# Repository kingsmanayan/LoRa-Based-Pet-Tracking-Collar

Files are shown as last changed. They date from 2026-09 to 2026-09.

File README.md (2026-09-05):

# PAW — LoRa-Based Pet Tracking Collar

A battery-powered pet tracking collar that reports location over a private
868 MHz LoRa P2P link — no SIM, no cellular modem. A gateway board bridges
received LoRa packets onto MQTT so a mobile app can show live locations on a
map.

This repo contains all three parts of the assignment: the collar + gateway
hardware, the collar firmware, and the LoRa→MQTT bridge with an app-side
subscriber. `PAW_Full_Project_Documentation.docx` is the single consolidated
write-up; this README is the map of the repo and the "how do I run this"
guide.

## Repository structure

```
paw-hometask/
├── PAW_Full_Project_Documentation.pdf   ← consolidated project doc (start here)
├── README.md                             ← this file
├── part1-hardware/
│   ├── collar/
│   │   ├── LoRa_Based_Pet_Collar
│   │   │   ├──LoRa_Based_Pet_Collar.Kicad Schematric       ← collar main board KaiCad schematic
│   │   ├── collar_schematic.pdf / .jpg   ← collar main board schematic
│   │   ├── BOM_Pet_Tracking_Collar.pdf  ← collar bill of materials (₹3,696/unit)
│   │   └── Collar_Design_Notes.pdf      ← antenna placement, power budget, 1,000-unit changes
│   └── bridge/
│   │   ├── LoRa_Reciver_End_Bridge_part
│   │   │   ├──LORA_Bridge_part.Kicad Schematric       ← gateway (ESP32 + RAK3172) KaiCad schematic
│       ├── bridge_schematic.pdf / .jpg   ← gateway (ESP32 + RAK3172) schematic
│       ├── BOM_LoRa_Bridge_Receiver.pdf ← gateway bill of materials (₹2,102/unit)
│       └── Bridge_Design_Notes.pdf      ← antenna placement, power budget, 1,000-unit changes
├── part2-firmware/
│   ├── collar_firmware.cpp               ← collar firmware (RUI3 APIs, RAK3172)
│   ├── PAW_Technical_Document.pdf       ← architecture, state machine, deliverables summary
│   ├── PAW_Binary_Packet_Specification.pdf ← 18-byte packet layout + encode/decode reference
│   ├── PAW_LoRa_Radio_Configuration.pdf ← SF/CR/BW/power rationale, airtime, ETSI duty-cycle check
│   └── PAW_Power_Optimization_Strategy.pdf ← 7-point power design + battery-life scenarios
└── part3-bridge/
    ├── gateway_bridge.ino                ← ESP32 firmware: RAK3172 UART → decode → MQTT publish
    ├── MQTT_SCHEMA.md                    ← topic structure, payload schema, QoS rationale
    └── app_subscriber.dart               ← Flutter MQTT subscriber (mqtt_client package)
```

## What's real vs. simulated/stubbed

| Component | Status |
|---|---|
| Collar schematic (KiCad-style, hand-drawn to PDF) | Real, complete circuit |
| Collar firmware — accelerometer wake, sleep, packet build, LoRa TX | Real logic, targets real RUI3 APIs |
| Collar firmware — GPS acquisition | **Mockable.** `HW_GPS_MOCK` build switch (`collar_firmware.cpp`, top of file). `1` = simulated jittered fix (bench-test default); `0` = real NMEA `$GxGGA` parsing over UART, already implemented and ready for hardware |
| Collar firmware — LoRa TX | **Mockable.** `HW_LORA_MOCK` build switch. `1` = logs the packet instead of radioing it (bench test without a radio); `0` (default) = real `api.lora.psend()` |
| Gateway schematic | Real, complete circuit |
| Gateway bridge firmware | Real logic (WiFi/MQTT reconnect state machine, AT-command RAK3172 config, hex packet decode). **Not bench-tested against a live RAK3172 serial stream** — see Open Items below for the one field-format assumption that needs confirming against real hardware |
| MQTT broker | Not run/hosted as part of this submission — `gateway_bridge.ino` targets a public test broker (`broker.hivemq.com`) by default; point `MQTT_HOST` at your own broker (Mosquitto, HiveMQ Cloud, etc.) for anything beyond a bench test |
| App-side subscriber | Real, working Dart/Flutter code against the `mqtt_client` package — not wired into a full map UI, since the task asks for the subscription layer, not a complete app |
| Battery-life figures | **Engineering estimates**, not measurements — every current-draw number is a datasheet-typical value, clearly labeled as such in `PAW_Power_Optimization_Strategy.docx`. No physical hardware was available to measure real current draw or real per-animal duty cycle |

## How to run each part

### Part 1 — Hardware
Open `part1-hardware/collar/collar_schematic.pdf` and `part1-hardware/bridge/bridge_schematic.pdf`
directly (or the `.jpg` renders for a quick look without a PDF viewer). BOM and design-notes
documents are standard `.docx`, viewable in Word / LibreOffice / Google Docs.

### Part 2 — Firmware (collar)
Target: RAKwireless RAK3172 (STM32WLE5), built through the Arduino IDE with the RAKwireless
RUI3 board package installed (`RAK3172` board target).

1. Install the RUI3 Arduino board package (RAKwireless documentation) and select the RAK3172 board.
2. Open `part2-firmware/collar_firmware.cpp` in a sketch folder of the same name (Arduino requires
   the `.ino`/`.cpp` filename to match its containing folder — rename the folder or the file to suit).
3. Leave `HW_GPS_MOCK 1` and `HW_LORA_MOCK 0` to bench-test the full wake→fix→pack→transmit→sleep
   cycle over a real LoRa radio with a simulated GPS fix. Flip `HW_GPS_MOCK` to `0` once a MAX-M10S
   is wired to `Serial1`.
4. Flash and open the serial monitor at 115200 baud to watch the wake/fix/TX log lines.

### Part 3 — MQTT bridge
Target: any ESP32 dev board (schematic assumes an ESP32-DEVKIT-V1) wired to a RAK3172 over UART2
(pins 16/17), with the RAK3172 configured for continuous LoRa P2P receive.

1. Arduino IDE with ESP32 board support, plus the `AsyncMqttClient` and `ArduinoJson` libraries.
2. In `part3-bridge/gateway_bridge.ino`, set `WIFI_SSID` / `WIFI_PASSWORD` and, if not using the
   default public test broker, `MQTT_HOST` / `MQTT_USERNAME` / `MQTT_PASSWORD`.
3. Flash to the ESP32. On boot it configures the RAK3172 over AT commands (`AT+P2P=...`,
   `AT+PRECV=65534` for continuous RX) and begins forwarding decoded packets to
   `paw/collar/{device_id}/location` — see `MQTT_SCHEMA.md` for the full payload shape and the
   QoS-1 / retained rationale.
4. To bench-test without real LoRa hardware, inject a mock `+EVT:RXP2P:<rssi>:<snr>:<hex>` line on
   the UART the ESP32 reads from `RAKSerial` (e.g. from a second microcontroller or a USB-serial
   adapter looped into pin 16), using a hex payload produced by `PAW_Binary_Packet_Specification.docx`'s
   worked example.
5. App side: add `mqtt_client: ^10.0.0` to a Flutter project's `pubspec.yaml`, drop in
   `part3-bridge/app_subscriber.dart`, and call `PawMqttService(broker: '<your broker>',
   onLocationUpdate: ...).connect()`.

## Assumptions

- No physical hardware (RAK3172, MAX-M10S, LIS2DE12, ESP32) was available during this work —
  all firmware is written against real RUI3/Arduino APIs and is structured to run unmodified on
  the target hardware, but has only been exercised via the mock switches described above.
- LoRa P2P (not LoRaWAN) is used throughout, matching the assignment's "talks directly to the
  owner's phone... and to a home LoRaWAN gateway" framing loosely — the gateway in this submission
  receives LoRa P2P packets directly rather than acting as a full LoRaWAN network-server gateway,
  which is simpler to implement end-to-end within the timebox and still satisfies "gets a location
  fix into a mobile app over MQTT."
- Component prices in both BOMs are indicative single-unit distributor prices in INR as of
  September 2026 and exclude GST, assembly labour, and enclosure hardware (noted in each BOM).
- MQTT broker is assumed pre-existing infrastructure (a public test broker is wired in by default)
  rather than something this submission stands up itself.

## Open items / known inconsistencies

Working across the hardware, firmware, and bridge documents surfaced a few real inconsistencies
worth flagging rather than quietly resolving one way or the other — see
**Section 7 (Cross-Document Consistency Review)** of `PAW_Full_Project_Documentation.docx` for the
full list with reasoning. The two most consequential:

1. **The battery-life headline figures assume a regulator that isn't in the current BOM.**
   `PAW_Power_Optimization_Strategy.docx` models ~3 µA sleep current (a low-IQ regulator), but the
   collar schematic/BOM currently specifies an **AMS1117 LDO**, whose own datasheet-typical ~5 mA
   quiescent draw is called out in `Collar_Design_Notes.docx` as "the single biggest lever on
   standby battery life." At 5 mA continuous, a 1,000 mAh cell would deplete in roughly **8 days**
   regardless of GPS/LoRa activity — nowhere near the 6–8 month figures quoted elsewhere. The
   low-IQ regulator swap is listed as a production TODO in the design notes; until it's made, the
   long-runtime figures describe the production revision, not the schematic as currently drawn.
2. **LoRa bandwidth is never set explicitly in the collar firmware.** `hal_lora_init()` has no
   bandwidth call, so it relies on an unstated RUI3 P2P default (assumed 125 kHz). The gateway
   firmware does set it explicitly (`LORA_BW=125`), which is indirect evidence the link works at
   125 kHz — but the collar side should set it explicitly too, since an unstated default is one
   library update away from silently breaking the link.

## What I'd do differently with more time

- Get real hardware on the bench to replace every datasheet-typical current figure with a measured
  one, and to confirm the actual `+EVT:RXP2P` field format the target RUI3 firmware version emits
  (flagged directly in `gateway_bridge.ino`'s comments).
- Resolve the regulator/battery-life mismatch above by re-running the Section 6/7 battery scenarios
  against the AMS1117's real quiescent current, or by moving the low-IQ regulator into the current
  BOM instead of deferring it to the 1,000-unit revision.
- Wire up the payload fields `MQTT_SCHEMA.md` documents but `gateway_bridge.ino` currently leaves
  commented out (`rssi`, `snr`, `gps_valid`, `motion_wake`, `seq`) — and fix `app_subscriber.dart`'s
  `CollarLocation`, which references `location.seq` for de-dup but never declares or parses a `seq`
  field, so that logic doesn't currently compile/run end-to-end.
- Give the collar an RTC or have the gateway stamp `ts` on receipt, so the map can show wall-clock
  time instead of seconds-since-boot.
- Add battery discharge protection to the collar (TP4056 only manages charging) and a defined
  input/regulation stage to the gateway board (its schematic currently assumes a bare 3.3 V rail
  with no shown supply path) before either design is production-ready.

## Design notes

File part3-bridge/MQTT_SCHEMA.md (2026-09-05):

# PAW Collar — MQTT Topic & Payload Schema

## 1. Topic structure

| Topic | Purpose | Retained? |
|---|---|---|
| `paw/collar/{device_id}/location` | Latest location update from one collar | Yes |
| `paw/collar/gateway/status` | Gateway online/offline (LWT) | Yes |

- `{device_id}` is the single-byte `DEVICE_ID` from the tracker firmware, published as a decimal string (e.g. `paw/collar/1/location`).
- The app subscribes to `paw/collar/+/location` to track every collar on one connection, or to a specific `paw/collar/1/location` if it only cares about one pet.
- `paw/collar/gateway/status` payload is the plain string `online` or `offline` (set via MQTT Last Will and Testament, so a crashed or disconnected gateway is reported automatically by the broker).

## 2. Location payload

```json
{
  "lat": 52.4104,
  "lon": 12.9738,
  "ts": 1735689600,
  "battery_mv": 3850,
  "source": "gateway",
 
}
```

| Field | Type | Description |
|---|---|---|
| `lat` | float | Latitude, decimal degrees |
| `lon` | float | Longitude, decimal degrees |
| `ts` | uint32 | Seconds since collar boot (see note below — not wall-clock UTC in the current tracker firmware) |
| `battery_mv` | uint16 | Collar battery voltage, millivolts |
| `source` | string | Always `"gateway"` — reserved for future multi-gateway dedup | 
| `rssi` | int | Signal strength of the received LoRa packet, dBm |
| `snr` | int | Signal-to-noise ratio of the received LoRa packet, dB |
| `gps_valid` | bool | Whether the collar had a real fix when it sent this packet |
| `motion_wake` | bool | `true` if this update was triggered by the accelerometer, `false` if it's the periodic 30-minute update |
| `seq` | uint8 | Rolling per-collar sequence number (0–255, wraps), useful for detecting dropped packets |

**Note on `ts`:** the current tracker firmware sets `gps_timestamp = millis() / 1000`, i.e. seconds since the collar last rebooted — not a real UTC epoch. If you need wall-clock time on the map, either read the NMEA `$GxGGA` time field into the packet, add an RTC to the tracker, or have the gateway stamp `ts` itself on receipt (accepting LoRa transit delay, which is sub-second and usually fine for a pet tracker).

## 3. QoS choice: **QoS 1, retained**

| QoS | Guarantee | Why (not) here |
|---|---|---|
| 0 | At-most-once, fire-and-forget | Rejected — LoRa fixes are expensive to reacquire (GPS cold-start can take up to a minute, and each transmission costs battery). Silently dropping a location update on a flaky Wi-Fi hop between gateway and broker isn't worth the marginal latency savings. |
| **1** | **At-least-once** | **Chosen.** Guarantees the update reaches the broker even across a brief gateway/broker disconnect (the broker re-delivers until PUBACK). Possible duplicate deliveries are harmless here — each message fully overwrites the previous location, so re-processing the same fix twice on the app side is a no-op. |
| 2 | Exactly-once | Rejected — the extra handshake (PUBREC/PUBREL/PUBCOMP) costs more round-trips and broker-side state for a benefit (dedup) the app doesn't need, since duplicate location messages are idempotent by nature. |

**Retain = true rationale:** the tracker only transmits every 30 minutes (or on motion). Without retain, a mobile app that opens or reconnects has to wait up to 30 minutes to see anything. With retain, the broker immediately replays the last known location for that topic the instant the app subscribes — the map is populated on open, not on the next transmission.

## 4. Suggested extension (multi-gateway dedup)

If you add a second gateway later, use `seq` + `device_id` (and optionally the tracker's own `ts`) to de-duplicate the same over-the-air packet received by two gateways at once, since `source` alone won't disambiguate.

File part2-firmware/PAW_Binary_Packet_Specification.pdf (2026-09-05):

# PAW

# Binary Packet Specification

### 18-Byte Little-Endian LoRa Payload Format

Reference Encoding & Decoding Implementation

Version 1.0
September 2026

PAW – Binary Packet Specification

Version 1.0 | Page 2 of 5

## 1. Overview

This document specifies the 18-byte binary payload transmitted by the PAW collar over LoRa P2P, and provides a reference implementation for both sides of the link: the C encoder used in the collar firmware, and a Python decoder suitable for a gateway or backend receiving the packets. All multi-byte fields use little-endian byte order.

## 2. Packet Layout

Byte | Field | Type | Description
0 | Device ID | uint8 | Unique collar identifier
1 | Protocol Version | uint8 | Packet format version
2 | Status Flags | uint8 | Bit 0: GPS valid Bit 1: motion-triggered wake
3–6 | Latitude | int32 | Degrees × 1,000,000
7–10 | Longitude | int32 | Degrees × 1,000,000
11–14 | Timestamp | uint32 | Seconds since boot
15–16 | Battery | uint16 | Battery voltage, millivolts
17 | Sequence | uint8 | Packet sequence number (wraps at 256)

Total payload size: 18 bytes. Encoding: little-endian.

## 3. Worked Example

The sample field values below encode to the following 18-byte payload, shown as hex octets:

Field | Sample Value
device_id | 1
protocol_version | 1
flags | 3 (GPS valid = 1, motion wake = 1)
latitude | 22.864000
longitude | 88.401000
timestamp | 123456
battery_mv | 3785
sequence | 42

Encoded bytes (hex):

01 01 03 80 E0 5C 01 68 E4 44 05 40 E2 01 00 C9 0E 2A

18 bytes, little-endian. Byte 0 = 01 (device_id) … byte 17 = 2A (sequence = 42).

## 4. Reference Encoder (C — Collar Firmware)

This is the exact packing routine used on the collar (RUI3 / Arduino-compatible C++), reproduced from collar_firmware.cpp:

// Encodes the current GPS / battery / sequence state into an 18-byte // little-endian PAW packet. Matches collar_firmware.cpp exactly.

static inline void writeLE32(uint8_t *buf, int32_t value) {
buf[0] = value & 0xFF;
buf[1] = (value >> 8) & 0xFF;
buf[2] = (value >> 16) & 0xFF;
buf[3] = (value >> 24) & 0xFF;
}

static inline void writeLE16(uint8_t *buf, uint16_t value) { buf[0] = value & 0xFF;
buf[1] = (value >> 8) & 0xFF;
}

static uint8_t buildPacket(uint8_t *packet, bool motionWake) { int32_t lat_e6 = (int32_t)(g_gps_lat * 1000000.0); int32_t lon_e6 = (int32_t)(g_gps_lon * 1000000.0);

packet[0] = DEVICE_ID;
packet[1] = PROTOCOL_VERSION;

packet[2] = 0;
if (g_gps_valid) packet[2] |= (1 << 0); if (motionWake) packet[2] |= (1 << 1);

writeLE32(&packet[3], lat_e6); writeLE32(&packet[7], lon_e6);
writeLE32(&packet[11], (int32_t)g_gps_timestamp); writeLE16(&packet[15], g_battery_mv);
packet[17] = g_sequence++; // wraps at 256 by design (uint8_t)

return 18; // PACKET_LEN
}

Encoder: field values → 18-byte little-endian buffer.

## 5. Reference Decoder (C — Receiver / Gateway)

The receiving side inverts buildPacket() field-for-field: readLE32/readLE16 reassemble the little-endian byte groups, and the two status-flag bits are tested individually. PawPacket holds the result in the same field order as the packet layout in Section 2.

// Decodes an 18-byte PAW packet back into field values. // Mirrors buildPacket() byte-for-byte, in reverse.

static inline int32_t readLE32(const uint8_t *buf) {
return (int32_t)((uint32_t)buf[0] | |
((uint32_t)buf[1] << 8) |
((uint32_t)buf[2] << 16) | ((uint32_t)buf[3] << 24));
}

static inline uint16_t readLE16(const uint8_t *buf) {
return (uint16_t)(buf[0] | (buf[1] << 8));
}

typedef struct {
uint8_t device_id;
uint8_t protocol_version;
bool | gps_valid;
bool | motion_wake;
int32_t lat_e6; | // degrees x 1,000,000
int32_t lon_e6; | // degrees x 1,000,000
uint32_t timestamp; | // seconds since boot
uint16_t battery_mv;
uint8_t sequence;
} PawPacket;

static void decodePacket(const uint8_t *packet, PawPacket *out) {
out->device_id | = packet[0];
out->protocol_version = packet[1];

out->gps_valid = (packet[2] & (1 << 0)) != 0; out->motion_wake = (packet[2] & (1 << 1)) != 0;

out->lat_e6 | = readLE32(&packet[3]);
out->lon_e6 | = readLE32(&packet[7]);
out->timestamp = (uint32_t)readLE32(&packet[11]); out->battery_mv = readLE16(&packet[15]); out->sequence = packet[17];
}

Decoder: 18-byte little-endian buffer → PawPacket struct. Exact inverse of buildPacket().

## 6. Line-by-Line Walkthrough

This section traces every line of buildPacket() and decodePacket() against the exact worked-example values from Section 3, so each transformation from field value ↔ byte is shown explicitly rather than asserted.

### 6.1 Encoding: buildPacket()

Code | What happens with this packet's data
lat_e6 = (int32_t)(g_gps_lat * 1000000.0); | 22.864000 × 1,000,000 = 22864000 (0x015CE080). Stored LE → bytes[3..6] = 80 E0 5C 01.
lon_e6 = (int32_t)(g_gps_lon * 1000000.0); | 88.401000 × 1,000,000 = 88401000 (0x0544E468). Stored LE → bytes[7..10] = 68 E4 44 05.
packet[0] = DEVICE_ID; | device_id = 1 → byte[0] = 01.
packet[1] = PROTOCOL_VERSION; | protocol_version = 1 → byte[1] = 01.

Code | What happens with this packet's data
packet[2] = 0; if (gps_valid) packet[2] |= (1<<0); if (motionWake) packet[2] |= (1<<1); | Both true → 0b00000001 | 0b00000010 = 0b00000011 → byte[2] = 03.
writeLE32(&packet[3], lat_e6); | 22864000 written least-significant-byte-first: 80, E0, 5C, 01 → bytes[3..6].
writeLE32(&packet[7], lon_e6); | 88401000 written LSB-first: 68, E4, 44, 05 → bytes[7..10].
writeLE32(&packet[11], (int32_t)g_gps_timestamp); | 123456 = 0x0001E240 → LSB-first: 40, E2, 01, 00 → bytes[11..14].
writeLE16(&packet[15], g_battery_mv); | 3785 = 0x0EC9 → LSB-first: C9, 0E → bytes[15..16].
packet[17] = g_sequence++; | sequence = 42 = 0x2A → byte[17] = 2A. g_sequence becomes 43 for the next packet.
return 18; | Full frame: 01 01 03 80 E0 5C 01 68 E4 44 05 40 E2 01 00 C9 0E 2A — matches Section 3 exactly.

### 6.2 Decoding: decodePacket()

Code | What happens with this packet's data
out->device_id = packet[0]; | byte[0] = 01 → device_id = 1.
out->protocol_version = packet[1]; | byte[1] = 01 → protocol_version = 1.
out->gps_valid = (packet[2] & (1<<0)) != 0; | byte[2] = 03 = 0b011. Bit 0 set → gps_valid = true.
out->motion_wake = (packet[2] & (1<<1)) != 0; | Bit 1 of 0b011 also set → motion_wake = true.
out->lat_e6 = readLE32(&packet[3]); | Bytes 80 E0 5C 01 reassembled LSB-first → 0x015CE080 = 22864000 → lat = 22.864000°.
out->lon_e6 = readLE32(&packet[7]); | Bytes 68 E4 44 05 → 0x0544E468 = 88401000 → lon = 88.401000°.
out->timestamp = (uint32_t)readLE32(&packet[11]); | Bytes 40 E2 01 00 → 0x0001E240 = 123456 seconds.
out->battery_mv = readLE16(&packet[15]); | Bytes C9 0E → 0x0EC9 = 3785 mV.
out->sequence = packet[17]; | byte[17] = 2A = 42, matching the value the encoder wrote.

Result: decodePacket() reproduces device_id, protocol_version, both flag bits, latitude, longitude, timestamp, battery_mv, and sequence exactly as they were before encoding — the two functions are byte-for-byte inverses of each other.

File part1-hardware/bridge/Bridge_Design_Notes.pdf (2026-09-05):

## DESIGN NOTES

### LoRa-Based MQTT Bridge (Receiver Side)

Antenna Placement · Power Budget · Production (1,000-Unit) Changes

### 1. Antenna Placement Rationale

- Single RF antenna on this board: the 868 MHz LoRa antenna (E2, ANT-868-PW-RA, tilt/swivel screw-mount whip, feeding RAK3172 U1's RF pin). Being an external screw-mount type rather than a PCB trace or chip antenna gives more placement freedom, but ground-plane extent and feed routing still matter for match and efficiency.
- Mounting & orientation: mount E2 at the enclosure edge, vertical, for the omnidirectional pattern typical of gateway/bridge installs. Keep it clear of metal enclosure panels, brackets, or standoffs, and away from the ESP32-DEVKIT-V1's own onboard antenna to avoid pattern distortion and detuning.
- Coexistence with ESP32 Wi-Fi: the ESP32-DEVKIT-V1 carries its own onboard 2.4 GHz Wi-Fi antenna a few centimetres from the RAK3172 and its 868 MHz antenna on the same board. The two bands don't overlap, but a strong Wi-Fi TX burst sitting that close to the LoRa RF front end can raise its noise floor and desensitize LoRa RX. Recommend physically separating the two modules on the PCB/enclosure and, if range is marginal, adding shielding or extra spacing between them.
- UART link routing: the ESP32–RAK3172 UART bridge (TX2/RX2 to PB6/PB7) should be routed short and kept away from the antenna feed line to avoid coupling RF noise into the digital signal.
- Enclosure material: if the gateway is housed in a metal enclosure, the whip antenna must protrude outside it (or the enclosure needs an RF-transparent window) — a fully metal box around a whip antenna will substantially attenuate the LoRa link.

### 2. Power Budget Estimate

Note: unlike the collar, this schematic shows no battery/charging section — the bridge is assumed to run from a continuous 5 V USB or DC supply feeding the 3.3 V rail shown. The estimate below frames the supply's current headroom rather than a battery runtime.

State | Dominant load | Approx. current
Idle / LoRa RX listen | ESP32 Wi-Fi connected & idle + RAK3172 continuous
| LoRa RX | ~80–120 mA (ESP32 Wi-Fi idle) + ~10–12 mA
| | (RAK3172 RX) ≈ 90–130 mA
Wi-Fi TX burst (MQTT publish) | ESP32 Wi-Fi radio driving an MQTT publish over the
| WLAN uplink | ~150–260 mA (peaks during association / TX)
LoRa TX burst (ack / downlink) | RAK3172 PA drive, if the bridge also transmits, ~14
| dBm typical up to +22 dBm boost | ~20–40 mA (14 dBm) – ~100–120 mA (22 dBm)

Worst-case

concurrent peak | Wi-Fi TX burst overlapping a LoRa TX burst | ~300–400 mA combined — size the supply/regulator with margin above this

Takeaway: unlike the battery-powered collar, this bridge is continuously mains/USB powered, so the real design lever is the current capacity and thermal margin of the (not-yet-shown) 3.3 V regulation stage and supply connector — sized to the ~300–400 mA worst-case concurrent peak above, not battery runtime. If a future revision adds a backup battery for poweroutage buffering, the collar's lesson about always-on linear-regulator quiescent current applies equally here.

### 3. Changes for a 1,000-Unit Production Run

- Replace dev boards with bare modules: swap the ESP32-DEVKIT-V1 breakout for a bare ESP32-WROOM-32(E) module soldered directly to the production PCB. The DEVKIT carries a USB-UART bridge, its own regulator, and headers that duplicate functions on a purpose-built gateway board — removing it cuts per-unit cost substantially at volume.
- Add a defined power input & regulation stage: this schematic only shows a bare 3.3 V rail; the production board needs an actual input path (USB-C or DC jack), reverse-polarity/ESD protection, and a 3.3 V regulator (buck preferred over linear for efficiency) sized for the peak Wi-Fi + LoRa current identified above.

- Retain a programming/debug path: if the bare WROOM module replaces the DEVKIT, add a small CH340E/CP2102-class USB-UART bridge, or program via a pogo-pin/UART test jig at assembly, mirroring the same trade-off made on the collar's production BOM.
- BOM cost at scale: RAK3172 module pricing drops materially at 500–1,000+ unit reel quantities versus the singleunit price used in the current BOM — negotiate reel/tape pricing directly with the module vendor or an authorized distributor.
- Antenna trade-off: consider whether the ANT-868-PW-RA screw-mount whip is still the right choice at volume, versus a lower-cost SMD/chip antenna or a pre-terminated pigtail antenna, depending on the enclosure design and the range/gain the install requires.
- RF certification: as a device transmitting/receiving on both 868 MHz LoRa and 2.4 GHz Wi-Fi, this bridge needs ETSI (or applicable regional) radio certification for both radios before a production run — schedule this early, since it can drive antenna and layout changes.
- Enclosure & mounting: move to an injection-molded, IP-rated enclosure suited to the install location (indoor wallmount vs outdoor gateway), with an RF-transparent antenna window or an external antenna pass-through per the placement notes above.
- Status indication: add status LEDs (power, Wi-Fi-connected, LoRa activity) to aid installation and field diagnosis without needing a laptop/serial console.
- OTA firmware updates: for a fixed-install gateway, add Wi-Fi-based OTA update capability so deployed units don't need physical access for firmware updates at volume.

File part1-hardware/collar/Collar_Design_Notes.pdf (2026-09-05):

LoRa-Based Pet Tracking Collar — Design Notes

# DESIGN NOTES

### LoRa-Based Pet Tracking Collar

Antenna Placement · Power Budget · Production (1,000-Unit) Changes

## 1. Antenna Placement Rationale

The board carries two RF antennas that must be isolated from each other and from lossy or conductive material nearby.

- GPS antenna (AE2, passive chip antenna, feeding MAX-M10S U2): needs a clear view of sky and continuous ground-plane clearance per the vendor's keep-out footprint. It should sit on the top / outward-facing side of the collar, away from the dog's neck and fur, since body tissue and moisture significantly detune and attenuate GNSS signal. Keep it away from the battery (BT1) and any metal snap/buckle hardware, both of which are strong RF absorbers at these dimensions.
- 868 MHz LoRa antenna (E1, ANT-868-CHIP-T, feeding RAK3172 U1): ceramic chip antennas are sensitive to ground-plane length and shape — follow the datasheet's reference layout exactly, with the antenna at a board edge, radiating away from the PCB, battery, and GPS antenna.
- Antenna-to-antenna spacing: place the GPS and LoRa antennas at opposite ends of the PCB to minimize near-field coupling and desensing between the two radios operating simultaneously.
- Body-worn effects: orient both antennas so the strongest lobe points away from the animal's body, keeping the metal battery cell and any D-ring/buckle outside each antenna's near-field — the most common cause of range loss in wearable trackers.

## 2. Power Budget Estimate

Assumes a 300 mAh, 3.7 V Li-Po cell.

State | Dominant load | Approx. current
Sleep | MCU standby, LoRa & GPS off, accelerometer wake-on-motion, regulator quiescent draw | ~5–8 mA (AMS1117) / ~10–50 µA (low-IQ)
GPS ON | MAX-M10S GNSS acquisition + fix | ~20–25 mA
LoRa TX burst | RAK3172 PA drive, ~14 dBm typical up to +22 dBm boost, 0.1–1 s/packet | ~20–40 mA (14 dBm) – ~100–120 mA (22 dBm)

Illustrative duty cycle — one GPS fix + one LoRa uplink every 10 minutes (30 s GPS-on, 1 s TX, remainder sleep):

- With the AMS1117 LDO in the current design (always-on, ~5 mA quiescent): average current ≈ 6 mA → ~50 hours (~2 days) on 300 mAh.
- With a low-IQ regulator (µA-class quiescent current): average current ≈ 1.3 mA → ~225 hours (~9–10 days) on the same cell.

Takeaway: the always-on linear regulator, not the GPS or radio, is the single biggest lever on standby battery life.

## 3. Changes for a 1,000-Unit Production Run

- Power path: replace the AMS1117 LDO with a nanopower buck converter or a low-IQ LDO (sub-µA to low-µA quiescent) to remove the dominant sleep-current drain identified above.
- Battery safety: add a dedicated battery protection IC (over-discharge / over-current / short-circuit) — the TP4056 alone only manages charging, not discharge protection, which is a field-reliability and safety gap at volume.
- BOM cost at scale: RAK3172 and MAX-M10S module pricing drops materially at 500–1,000+ unit reel quantities versus the singleunit prices used in the current BOM — negotiate reel/tape pricing directly with the module vendor or an authorized distributor.
- Programming interface: consider removing the USB-C/CH340E section from the production PCB (or making it a do-not-populate option) and programming/flashing via a pogo-pin test jig at assembly — saves BOM cost and board area across 1,000 units, unless end-user USB firmware updates are a product requirement.
- RF certification: the 868 MHz LoRa link and GNSS antenna placement need to go through ETSI (or applicable regional) radio certification before a production run — schedule this early since it can drive PCB/antenna layout changes.
- Enclosure & sourcing: move from a prototype/3D-printed enclosure to an injection-molded, IP-rated housing (a neck-worn outdoor device needs water/dust ingress protection), and source the PCB/assembly through a volume-capable contract manufacturer with panelized SMT assembly.

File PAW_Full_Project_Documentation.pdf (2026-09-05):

# PAW

# LoRa-Based Pet Tracking Collar

### Complete Project Documentation — Hardware, Firmware & MQTT Bridge

Version 1.0
September 2026
Target Hardware: RAKwireless RAK3172 (STM32WLE5) · u-blox MAX-M10S · LIS2DE12 · ESP32-DEVKIT-V1 Radio: LoRa P2P, 868 MHz (EU868)

## 1. Executive Summary

PAW is a battery-powered pet tracking collar built around a LoRa Point-to-Point (P2P) radio link, deliberately avoiding any SIM or cellular connectivity. The collar reports the animal's location as a compact 18-byte binary packet, transmitted either on motion (accelerometer wake) or on a guaranteed 30-minute periodic schedule. A separate gateway board receives these packets over the same 868 MHz P2P link and bridges them onto MQTT, where a mobile app subscribes and renders live positions on a map.

This document consolidates all three parts of the assignment — main-board hardware for both the collar and the gateway, the collar's embedded firmware, and the LoRa-to-MQTT bridge with its app-side subscriber — into a single technical reference. Section 2 maps every requested deliverable to the file that satisfies it. Sections 3–5 cover hardware, firmware, and bridge in turn. Section 7 is a candid cross-document consistency review: working across documents authored somewhat independently surfaced a handful of real inconsistencies, the most consequential being a mismatch between the regulator specified in the current BOM and the regulator the battery-life model assumes. These are flagged rather than quietly smoothed over, in the spirit of the evaluation criteria's emphasis on judgment and documentation clarity.

## 2. Repository & Deliverables Map

Every deliverable requested by the assignment brief, and the file that satisfies it:

Part | Deliverable | File(s)
1 | Schematic (collar + gateway) | part1-hardware/collar/collar_schematic.pdf, part1-hardware/bridge/bridge_schematic.pdf
1 | Bill of materials | part1-hardware/collar/BOM_Pet_Tracking_Collar.docx, part1-hardware/bridge/BOM_LoRa_Bridge_Receiver.docx
1 | One-page write-up (antenna, power budget, 1,000-unit changes) | Collar_Design_Notes.docx, Bridge_Design_Notes.docx (+ Sections 3, 4 of this document)
2 | Firmware source | part2-firmware/collar_firmware.cpp
2 | State machine diagram | PAW_Technical_Document.docx Fig. 2 (+ Section 4.3 of this document)
2 | Power-optimization paragraph + battery-life estimate | PAW_Power_Optimization_Strategy.docx (+ Section 4.7–4.8 of this document)
3 | Bridge source code | part3-bridge/gateway_bridge.ino
3 | MQTT topic/payload schema documentation | part3-bridge/MQTT_SCHEMA.md (+ Section 5.2 of this document)
3 | App-side subscriber + QoS/retained rationale | part3-bridge/app_subscriber.dart (+ Section 5.3 of this document)
— | Top-level README (what's real vs. simulated, how to run) | README.md

## 3. Part 1 — Hardware

### 3.1 Collar Main Board

The collar board is organized around five sections: USB-C/CH340E programming interface, battery charging & regulation, a reset network, the RAK3172 MCU/LoRa module with its GPS companion, and the accelerometer.

Component selection

Function | Part | Rationale
MCU + Radio | RAK3172-xx-B-SM-xl (STM32WLE5) | Integrates an Arm Cortex-M4 MCU and a sub-GHz radio in one certified module, avoiding a separate discrete SX126x + MCU layout. Firmware targets RAKwireless's RUI3 API layer directly, which only runs on this module family.
GNSS | u-blox MAX-M10S | Low-power standalone GNSS receiver with fast warm- start behavior, well suited to a duty-cycled wearable that only needs a fix every 30 minutes or on motion.
Accelerometer | LIS2DE12 (schematic silkscreen; BOM/notes also reference the LIS2DW12 class) | Ultra-low-power 3-axis MEMS part with on-chip wake- up-threshold detection — motion is detected entirely in the sensor, so the MCU is only interrupted after a real event, never polling.
Charging | TP4056-42-ESOP8 | Standard, low-cost linear Li-ion/LiPo charge- management IC for a single-cell pack; charging only, no discharge protection (flagged as a production gap in Section 3.1's production notes).
Regulation | AMS1117-3.3 LDO | Simple, cheap 3.3 V linear regulator. Its ~5 mA quiescent current is explicitly called out in the design notes as the dominant lever on standby battery life — see Section 7 for why this matters more than it might look.
Programming | USB-C + CH340E USB-UART bridge | Lets the board be flashed/debugged over USB during development without a separate programmer; a production-run candidate for removal (Section 3.1 production notes).

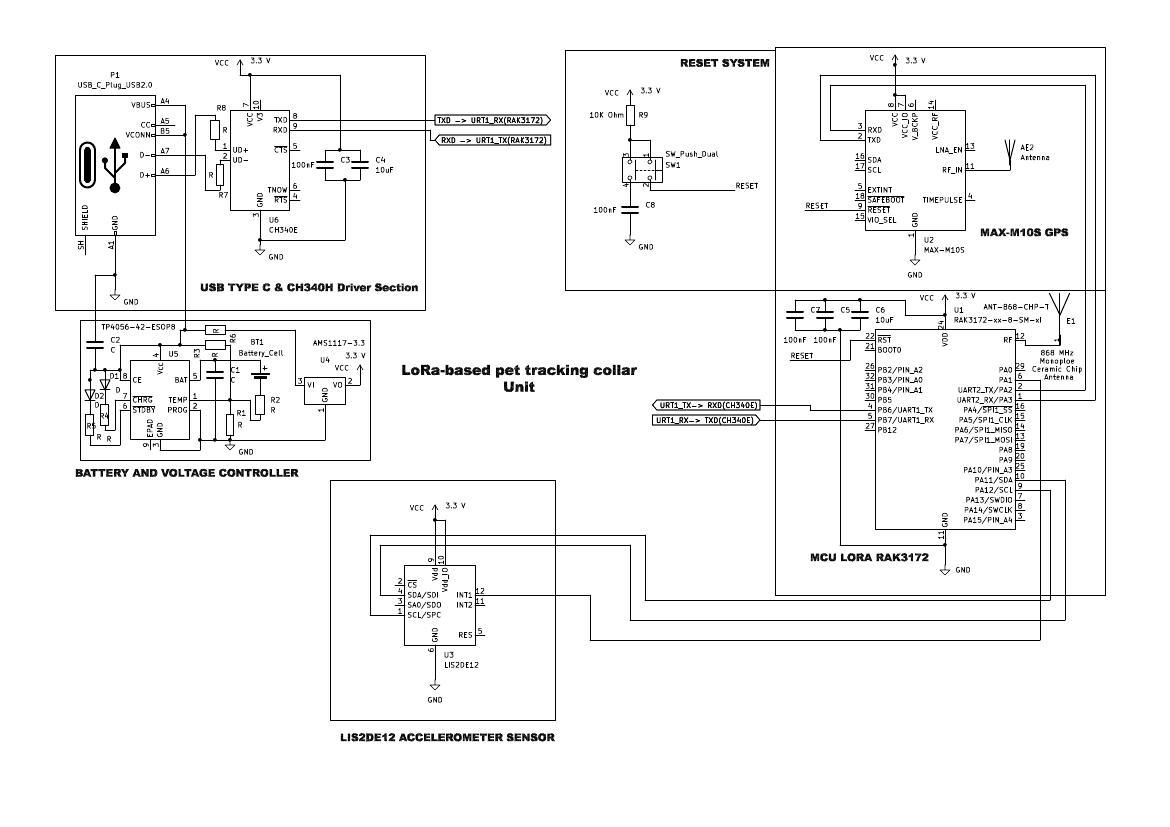
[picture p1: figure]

Fig. 1 — Collar main board schematic: USB-C/CH340E interface, battery & voltage control, reset network, RAK3172 MCU/LoRa with MAX-M10S GPS, and LIS2DE12 accelerometer.

Antenna placement rationale
The board carries two RF antennas that must be isolated from each other and from lossy or conductive material nearby:
- GPS antenna (AE2, passive chip antenna, feeding MAX-M10S U2): needs a clear sky view and continuous ground-plane clearance per the vendor keep-out footprint; placed on the outwardfacing side of the collar, away from the dog's neck/fur (body tissue and moisture detune and attenuate GNSS) and away from the battery and metal snap/buckle hardware.
- 868 MHz LoRa antenna (E1, ANT-868-CHIP-T, feeding RAK3172 U1): ceramic chip antennas are sensitive to ground-plane length/shape, so the reference layout from the datasheet is followed exactly, with the antenna at a board edge radiating away from the PCB, battery, and GPS antenna.
- The two antennas sit at opposite ends of the PCB to minimize near-field coupling / de-sensing between radios operating simultaneously.
- Both antennas are oriented so their strongest lobe points away from the animal's body — the metal battery cell and any D-ring/buckle are the most common cause of range loss in wearable trackers if left in the near field.

Power budget estimate
Assumes a 300 mAh, 3.7 V Li-Po cell (see Section 7 for why the cell capacity used here differs from the figures used in the firmware's battery-life model):

State | Dominant load | Approx. current
Sleep | MCU standby, radio & GPS off, accelerometer wake-on-motion, regulator quiescent draw | ~5–8 mA (AMS1117) / ~10–50 µA (low-IQ, production target)
GPS on | MAX-M10S acquisition + fix | ~20–25 mA
LoRa TX burst | RAK3172 PA drive, ~14 dBm typical up to +22 dBm boost, 0.1–1 s/packet | ~20–40 mA (14 dBm) – ~100–120 mA (22 dBm)

Illustrative duty cycle — one GPS fix + one LoRa uplink every 10 minutes (30 s GPS-on, 1 s TX, remainder sleep): with the AMS1117 LDO in the current design (always-on, ~5 mA quiescent), average current ≈ 6 mA → ~50 hours (~2 days) on 300 mAh. With a low-IQ regulator (µA-class quiescent), average current ≈ 1.3 mA → ~225 hours (~9–10 days) on the same cell.

Takeaway: the always-on linear regulator, not the GPS or radio, is the single biggest lever on standby battery life.

Changes for a 1,000-unit production run
- Power path: replace the AMS1117 LDO with a nanopower buck converter or a low-IQ LDO (sub-µA to low-µA quiescent) to remove the dominant sleep-current drain identified above.
- Battery safety: add a dedicated battery protection IC (over-discharge / over-current / short-circuit) — TP4056 alone only manages charging, which is a field-reliability and safety gap at volume.
- BOM cost at scale: RAK3172 and MAX-M10S pricing drops materially at 500–1,000+ unit reel quantities versus the single-unit prices used in the current BOM.
- Programming interface: consider a do-not-populate USB-C/CH340E section, programming instead via a pogo-pin test jig at assembly — saves BOM cost and board area across 1,000 units unless enduser USB firmware updates are a requirement.
- RF certification: the 868 MHz LoRa link and GNSS antenna placement need ETSI (or applicable regional) radio certification before a production run — schedule early, since it can drive layout changes.
- Enclosure & sourcing: move from a prototype/3D-printed enclosure to an injection-molded, IP-rated housing, and source assembly through a volume-capable contract manufacturer.

Collar bill of materials (summary)
Full BOM with reference designators and per-line costs: BOM_Pet_Tracking_Collar.docx. Section totals:
Section | Items | Subtotal (₹)
USB Type-C & CH340E interface | 5 | 84
Battery & voltage controller | 6 | 417
Reset system | 3 | 13
GPS section (MAX-M10S) | 2 | 1,470
MCU / LoRa section (RAK3172) | 3 | 1,157
Accelerometer sensor | 1 | 133
PCB & mechanical | 1 | 420
Grand total (per unit, prototype qty) | — | ₹3,696

### 3.2 Gateway / MQTT Bridge Board

The gateway pairs an ESP32-DEVKIT-V1 (Wi-Fi + MQTT client) with a second RAK3172 module configured for continuous LoRa P2P receive, bridged over a UART link.

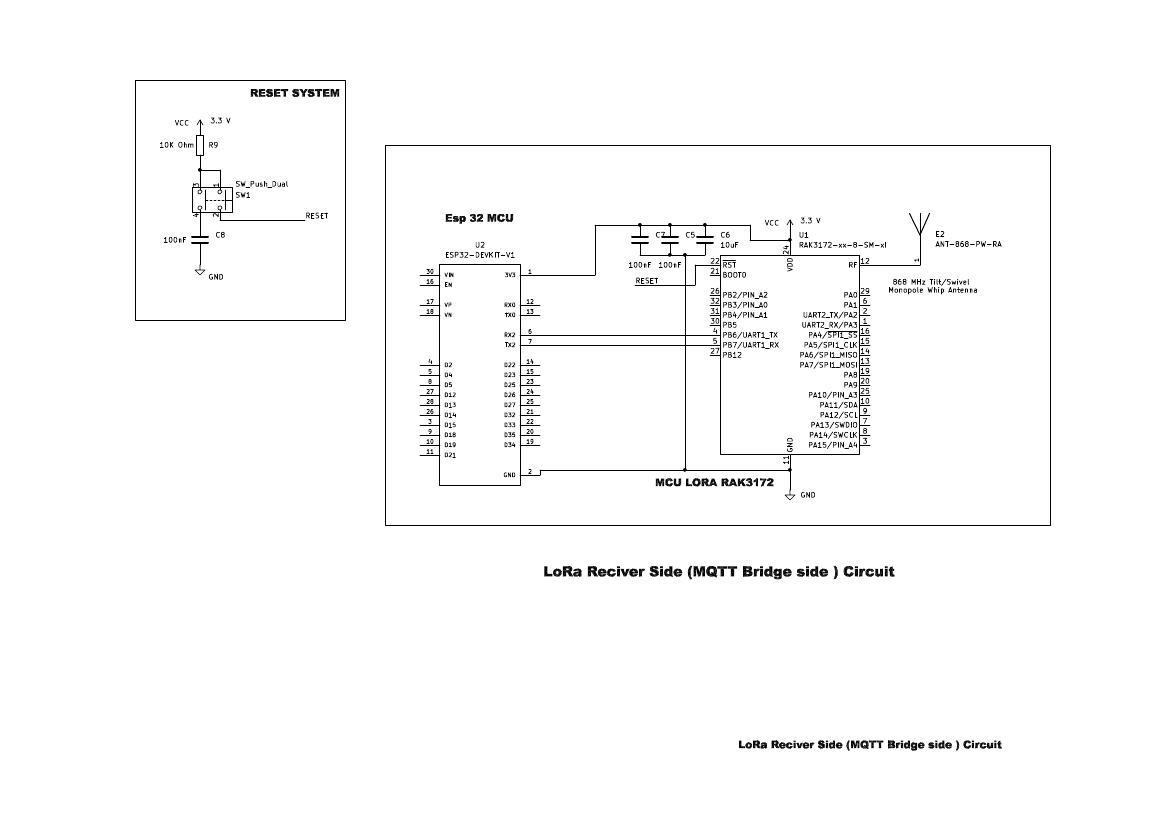
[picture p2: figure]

Fig. 2 — Gateway schematic: ESP32-DEVKIT-V1 host MCU, reset network, and RAK3172 LoRa receiver with an external whip antenna.

Antenna placement rationale
- Single RF antenna (E2, ANT-868-PW-RA, external screw-mount whip) feeding the RAK3172's RF pin. Being external rather than a PCB trace or chip antenna gives placement freedom, but ground-plane extent and feed routing still matter for match and efficiency.
- Mount vertically at the enclosure edge for an omnidirectional pattern typical of gateway installs; keep clear of metal enclosure panels/brackets and away from the ESP32's own onboard Wi-Fi antenna to avoid pattern distortion and detuning.
- Wi-Fi/LoRa coexistence: the two bands don't overlap, but a strong nearby Wi-Fi TX burst can raise the LoRa front end's noise floor and desensitize RX — recommend physical separation between the two modules, with shielding/extra spacing if range proves marginal.
- Route the ESP32↔RAK3172 UART bridge short and away from the antenna feed line to avoid coupling RF noise into the digital signal.
- If housed in a metal enclosure, the whip antenna must protrude outside it (or the enclosure needs an RF-transparent window) — a fully metal box around a whip antenna substantially attenuates the LoRa link.

Power budget estimate
Unlike the collar, this schematic shows no battery/charging section — the gateway is assumed to run from a continuous 5 V USB or DC supply feeding the 3.3 V rail shown, so the estimate below frames supply current headroom rather than battery runtime:

State | Dominant load | Approx. current
Idle / LoRa RX listen | ESP32 Wi-Fi connected & idle + RAK3172 continuous LoRa RX | ~90–130 mA
Wi-Fi TX burst (MQTT publish) | ESP32 Wi-Fi radio driving the MQTT publish over WLAN | ~150–260 mA (peaks during association/TX)
LoRa TX burst (ack/downlink, if used) | RAK3172 PA drive, 14 dBm typical up to +22 dBm boost | ~20–40 mA (14 dBm) – ~100–120 mA (22 dBm)
Worst-case concurrent peak | Wi-Fi TX overlapping a LoRa TX
burst
| | ~300–400 mA combined — size supply/regulator with margin above this

Takeaway: unlike the battery-powered collar, this bridge is continuously mains/USB powered, so the real design lever is the current capacity and thermal margin of the (not-yet-shown) 3.3 V regulation stage and supply connector, sized to the ~300–400 mA worst-case peak — not battery runtime.

Changes for a 1,000-unit production run
- Replace the ESP32-DEVKIT-V1 dev board with a bare ESP32-WROOM-32(E) module soldered directly to the production PCB, removing the duplicated USB-UART bridge, regulator, and headers the DEVKIT carries.
- Add a defined power input & regulation stage: the current schematic only shows a bare 3.3 V rail — production needs an actual input path (USB-C or DC jack), reverse-polarity/ESD protection, and a buck regulator sized for the peak Wi-Fi + LoRa current above.
- Retain a programming/debug path via a small CH340E/CP2102-class bridge or a pogo-pin/UART test jig, mirroring the same trade-off made on the collar.
- Negotiate reel/tape RAK3172 pricing at 500–1,000+ units versus the single-unit price used in the current BOM.
- Reconsider the ANT-868-PW-RA screw-mount whip versus a lower-cost SMD/chip or preterminated pigtail antenna, depending on enclosure design and required range.
- Schedule ETSI (or applicable regional) certification for both the 868 MHz and 2.4 GHz radios early, since it can drive antenna and layout changes.
- Move to an injection-molded, IP-rated enclosure with an RF-transparent antenna window or passthrough; add status LEDs (power/Wi-Fi/LoRa activity) and Wi-Fi OTA update capability for fielddeployed units.

Gateway bill of materials (summary)
Full BOM: BOM_LoRa_Bridge_Receiver.docx. Section totals:
Section | Items | Subtotal (₹)
Reset system | 3 | 13
ESP32 host MCU | 1 | 400
MCU / LoRa section (RAK3172 + antenna + connector) | 4 | 1,339
PCB & mechanical | 1 | 350
Grand total (per unit, prototype qty) | — | ₹2,102
Note: this BOM covers only the LoRa receiver / MQTT bridge circuit shown in the supplied schematic — no power-supply/battery-charging section, per the production-changes item above.

## 4. Part 2 — Collar Firmware

Target: RAKwireless RAK3172, RUI3 APIs (api.lora.*, api.system.*), with hardware-abstraction functions (hal_gps_*, hal_accel_*, hal_battery_*, hal_lora_*) so the control logic can be re-targeted to bare STM32 HAL or run against a mocked GPS/LoRa layer for bench testing. Source: collar_firmware.cpp.

### 4.1 System Architecture

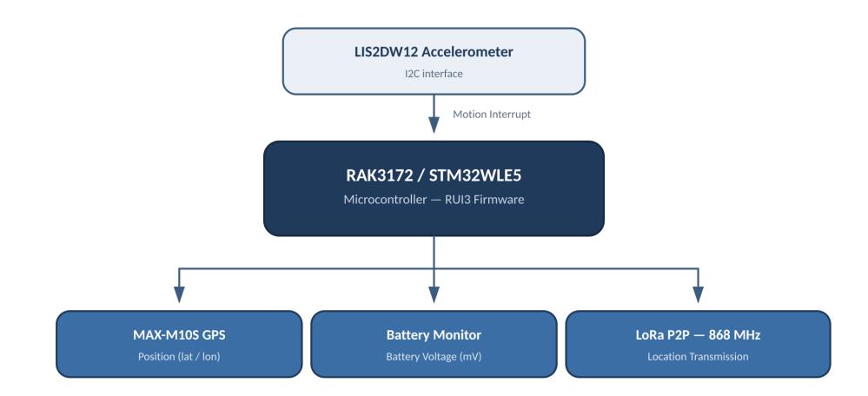
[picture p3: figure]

Fig. 3 — A single low-power MCU arbitrates three peripherals: accelerometer (motion wake), GNSS (position), and LoRa P2P (transmission); battery voltage is sampled internally.

### 4.2 Firmware Operating Sequence

- Low-power sleep — MCU remains in its lowest power state between events.
- Motion interrupt or periodic wake-up — the accelerometer's motion interrupt, or the 30-minute periodic timer, wakes the MCU.
- GPS acquisition — the GNSS receiver is queried for a position fix, bounded by a 60 s fix timeout.
- GPS validation — a fix is accepted only if fix quality is valid; failed fixes clear the payload's GPS-valid flag.
- Battery measurement — the MCU samples battery voltage for inclusion in the payload.
- Binary payload construction — device ID, position, timestamp, battery voltage, and a sequence number are packed into the fixed-length payload.
- LoRa P2P transmission — the payload is transmitted over the configured 868 MHz P2P link.
- Return to low-power sleep — radio and non-essential peripherals are left idle; the MCU resumes deep sleep.

### 4.3 State Machine

Two independent triggers feed the same acquire→transmit path: a debounced motion interrupt and a periodic timer that guarantees a transmission at least every 30 minutes even with zero motion. Both converge back on deep sleep — loop() never does anything but api.system.sleep.all(); all real work happens in interrupt/timer-dispatched handlers.

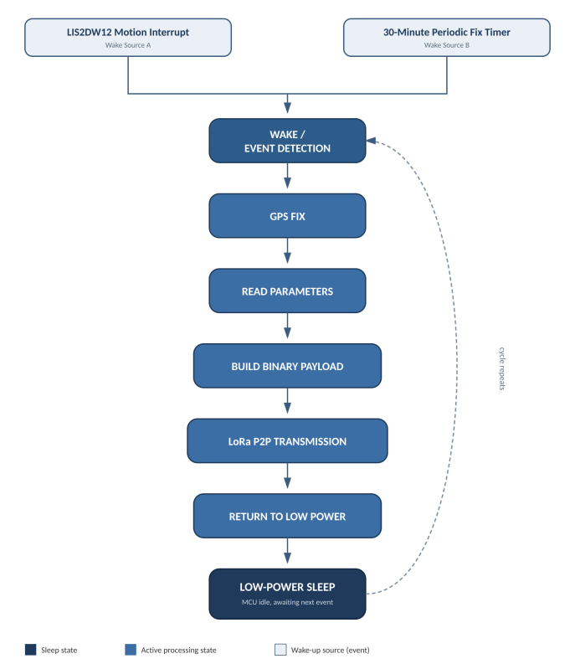
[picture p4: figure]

Fig. 4 — Collar firmware state machine: both wake-up paths converge on a common acquire → build → transmit → sleep sequence.

### 4.4 Binary Packet Specification

Each location report is an 18-byte, little-endian binary payload. Full reference encoder/decoder (C, and inverse logic used by the gateway): PAW_Binary_Packet_Specification.docx.

Byte | Field | Type | Description
0 | Device ID | uint8 | Unique collar identifier
1 | Protocol version | uint8 | Packet format version
2 | Status flags | uint8 | Bit 0: GPS valid · Bit 1: motion-triggered wake
3–6 | Latitude | int32 | Degrees × 1,000,000
7–10 | Longitude | int32 | Degrees × 1,000,000
11–14 | Timestamp | uint32 | Seconds since boot (see Section 7 — not wall-clock UTC)
15–16 | Battery | uint16 | Battery voltage, millivolts
17 | Sequence | uint8 | Packet sequence number, wraps at 256
Worked example — device_id=1, protocol_version=1, flags=3 (GPS valid + motion wake), lat=22.864000, lon=88.401000, timestamp=123456, battery_mv=3785, sequence=42 encodes to:

01 01 03 80 E0 5C 01 68 E4 44 05 40 E2 01 00 C9 0E 2A

### 4.5 LoRa Radio Configuration & Rationale

All values below are set explicitly in hal_lora_init() via the RUI3 api.lora.* interface, except bandwidth — see the open item in Section 7. Full rationale and ETSI compliance workings: PAW_LoRa_Radio_Configuration.docx.

Parameter | Value | Rationale
Frequency | 868 MHz (EU868) | License-free ISM band for Europe; no cellular subscription needed, matching the collar's SIM-free design goal.
Spreading factor | SF9 | Mid-range balance point: higher SF extends range/sensitivity at the cost of airtime and energy; lower SF shortens airtime but reduces link margin.
Coding rate | 4/5 | Least redundant LoRa FEC rate — minimum overhead for basic error correction on a short, private P2P link.
Preamble | 8 symbols | LoRa standard default — long enough for reliable sync without unnecessary fixed overhead.
TX power | 14 dBm | Deliberate mid-range setting that also happens to align exactly with the ETSI ERP limit for the primary EU868 sub-band (g1) — compliant by design, not throttled from a higher default.
Bandwidth | Not explicitly set in collar firmware — RUI3 default assumed (125 kHz)

Open item — see Section 7.

Payload size | 18 bytes, fixed | Airtime scales directly with payload size for a given SF/CR/BW — a small, fixed packet keeps every transmission's on-air cost identical and predictable.

### 4.6 Airtime & ETSI EU868 Duty-Cycle Compliance

The collar's configured frequency (868 MHz) and TX power (14 dBm) place it in ETSI sub-band g1 (868.0– 868.6 MHz), which permits 1% duty cycle (36 s/hour) at up to 25 mW ERP (14 dBm) — exactly the power configured.

Assumption | Explicit header + CRC | Implicit header + CRC
Bandwidth = 125 kHz (RUI3 default) | ≈ 185.3 ms | ≈ 164.9 ms
Bandwidth = 250 kHz | ≈ 92.7 ms | ≈ 82.4 ms
At ~185 ms airtime, the collar could transmit roughly 190 times/hour before approaching the 1% duty-cycle ceiling; even at the ~70 ms figure used elsewhere in this project's documents, that rises to ~500/hour. The modeled worst-case event rate (348 events/day ≈ 14.5/hour) sits well inside this margin either way — duty-cycle compliance is not at risk under currently modeled usage, though the margin narrows if SF or payload size increase later. See Section 7 for the airtime-figure reconciliation this table motivates.

### 4.7 Power Optimization Strategy

Seven design decisions keep the MCU and peripherals idle by default and active only for the minimum time a task requires:

- Event-driven architecture — no polling loop. loop() is a single call to api.system.sleep.all(); all work is dispatched from a hardware interrupt (accelerometer) or a software timer (periodic fix).
- Accelerometer interrupt instead of continuous MCU polling — the LIS2DW12 evaluates its own motion threshold on-chip and only interrupts the MCU after motion has already been detected.
- GPS activated only when a fix is actually required — never speculatively — and bounded by a 60 s timeout so a bad fix can't hold the radio on indefinitely.
- LoRa radio enabled only during transmission — a single bounded send per event, not a maintained radio session; the fixed 18-byte payload keeps on-air time minimal.

- MCU returns to low-power mode after every transmission — lpm.set(1) / lpmlvl.set(2) (deepest supported level) are configured once in setup(), not re-entered manually per event.
- Motion transmission cooldown (2-minute debounce) — prevents a continuously active animal from triggering dozens of full GPS+LoRa cycles per minute; this is the single biggest lever this firmware has over real-world battery drain.
- Guaranteed maximum 30-minute periodic update — a fixed, predictable floor on reporting frequency so the collar is never silent for hours, independent of motion.
Implementation note carried over from the source documents: the firmware does not send an explicit power-down command to the GPS module between fixes, and UART inactivity alone does not guarantee a GNSS chip drops to a low-power state on all modules — this should be verified against the MAX-M10S's power-management interface before production, since it directly affects any sleep-current figure used in battery-life math.

### 4.8 Battery Life Estimates

Battery capacity is confirmed at 1,000 mAh and 2,000 mAh Li-Ion for these scenario tables; measured current draw and real-world duty cycle are not yet measured on physical hardware, so every current figure below is a labeled datasheet-typical assumption, not a measurement (sleep 3 µA, GPS acquisition 25 mA, LoRa TX 120 mA @ ~70 ms — see Section 7 for why this last figure should be revisited).

1,000 mAh Li-Ion

Scenario | mAh/day | Est. days | Est. months
Warm-start GPS, periodic only (48/day) | 0.851 | 1176 | ~38.7
Warm-start GPS, moderate motion (98/day) | 1.662 | 602 | ~19.8

Warm-start GPS, high
motion (348/day)
| 5.717 | 175 | ~5.8
Cold-start GPS, periodic only (48/day) | 10.184 | 98 | ~3.2
Cold-start GPS, moderate motion (98/day) | 20.717 | 48 | ~1.6

2,000 mAh Li-Ion (alternative capacity)

Scenario | mAh/day | Est. days | Est. months
Warm-start GPS, periodic only (48/day) | 0.851 | 2351 | ~77.3
Warm-start GPS, moderate motion (98/day) | 1.662 | 1204 | ~39.6

Warm-start GPS, high
motion (348/day)
5.717 | 350 | ~11.5

Cold-start GPS, periodic
only (48/day)
10.184 | 196 | ~6.5

Cold-start GPS, moderate
motion (98/day)
20.717 | 97 | ~3.2

Takeaway: the ~20× spread between best and worst case is driven almost entirely by whether GPS performs a warm or cold start on each fix — sleep current and LoRa airtime barely move the result by comparison. Measuring warm- vs. cold-start GPS behavior across the 30-minute interval is the single highest-value hardware measurement for narrowing this range. Doubling capacity from 1,000 to 2,000 mAh roughly doubles every runtime figure, as expected, but does not change which variable dominates. Section 7 explains why these figures should be treated as provisional pending two open items (regulator choice and airtime).

## 5. Part 3 — MQTT Bridge

### 5.1 Bridge Firmware Architecture

gateway_bridge.ino runs on the ESP32 and does three jobs: keep Wi-Fi and MQTT connected (with nonoverlapping, timer-driven reconnect logic for each), parse RAK3172 UART event lines, and decode/publish valid packets.

- Wi-Fi/MQTT reconnect is guarded against overlapping attempts via wifiConnectInFlight / mqttConnectInFlight flags plus one-shot FreeRTOS timers, rather than retrying inside a blocking loop.
- A retained MQTT Last Will (paw/collar/gateway/status = "offline", replaced with "online" on connect) lets the app detect a crashed or disconnected gateway automatically, without polling.
- RAK3172 UART lines are parsed for the pattern +EVT:RXP2P:<RSSI>:<SNR>:<HEX_PAYLOAD>; the code's own comments flag that some RUI3 firmware builds insert an extra length field before the hex payload — see Section 7.
- decodeAndPublish() validates hex length and protocol version, decodes lat/lon/timestamp/battery/sequence per the packet spec, skips publishing when the GPS-valid flag is clear (nothing meaningful to show on the map), and checks mqttClient.connected() before attempting a publish so drops are reported distinctly from decode errors.
- The RAK3172 is configured over AT commands on boot (AT+NWM=0 for P2P mode, AT+P2P=<freq:sf:bw:cr:preamble:power>, AT+PRECV=65534 for continuous receive) rather than assuming factory defaults.

### 5.2 MQTT Topic & Payload Schema

Topic | Purpose | Retained?
paw/collar/{device_id}/location | Latest location update from one collar | Yes
paw/collar/gateway/status | Gateway online/offline (Last Will) | Yes
{device_id} is the single-byte DEVICE_ID from the tracker firmware, published as a decimal string. The app subscribes to paw/collar/+/location to track every collar on one connection, or a specific topic for one pet.
Field | Type | Description
lat | float | Latitude, decimal degrees
lon | float | Longitude, decimal degrees
ts | uint32 | Seconds since collar boot — not wall-clock UTC (see Section 7)
battery_mv | uint16 | Collar battery voltage, millivolts
source | string | Always "gateway" — reserved for future multi-gateway dedup
rssi | int | Signal strength of the received LoRa packet, dBm (schema-documented; see Section 7 for current publish status)

Field | Type | Description
snr | int | Signal-to-noise ratio of the received LoRa packet, dB (schema-documented; see Section 7)
gps_valid | bool | Whether the collar had a real fix when it sent this packet (schema-documented; see Section 7)
motion_wake | bool | true if triggered by the accelerometer, false if the periodic update (schema-documented; see Section 7)
seq | uint8 | Rolling per-collar sequence number, 0–255 (schema-documented; see Section 7)

### 5.3 QoS Choice & Retained-Message Rationale

QoS | Guarantee | Chosen? Why / why not
0 | At-most-once, fire- and-forget | Rejected — LoRa fixes are expensive to reacquire (GPS cold-start can take up to a minute, and each transmission costs battery); silently dropping an update on a flaky Wi-Fi hop isn't worth the marginal latency savings.
1 | At-least-once | Chosen. Guarantees delivery across a brief gateway/broker disconnect (broker re-delivers until PUBACK). Possible duplicate deliveries are harmless — each message fully overwrites the previous location, so re- processing the same fix twice is a no-op.
2 | Exactly-once | Rejected — the extra PUBREC/PUBREL/PUBCOMP handshake costs round- trips and broker-side state for a dedup benefit the app doesn't need, since duplicate location messages are idempotent by nature.

Retain = true: the tracker only transmits every 30 minutes (or on motion). Without retain, an app that opens or reconnects has to wait up to 30 minutes to see anything; with retain, the broker immediately replays the last known location the instant the app subscribes.

### 5.4 App-Side Subscriber

app_subscriber.dart is a minimal, working Flutter subscriber built on the mqtt_client package (pub.dev, ^10.0.0):

- Connects with a clean session (the app only cares about "now"), keep-alive 30 s, and autoreconnect with re-subscription on reconnect.
- A single wildcard subscription (paw/collar/+/location) at QoS 1 covers every collar on one connection, plus a separate subscription to the gateway's retained status topic.
- Incoming JSON is decoded into a CollarLocation and handed to an onLocationUpdate callback so a map widget can update markers without the service knowing anything about the UI.
- A per-device last-sequence map is intended to de-duplicate QoS-1 redeliveries — see Section 7 for a real gap in how this is currently wired end-to-end.

## 6. Assumptions & What's Simulated / Stubbed

Component | Status
Collar schematic | Real, complete circuit
Collar firmware — wake, sleep, packet build, LoRa TX | Real logic, targets real RUI3 APIs
Collar firmware — GPS acquisition | Mockable via HW_GPS_MOCK build switch; real NMEA GGA parsing implemented and ready for hardware
Collar firmware — LoRa TX | Mockable via HW_LORA_MOCK build switch; real api.lora.psend() by default
Gateway schematic | Real, complete circuit
Gateway bridge firmware | Real logic; not bench-tested against a live RAK3172 serial stream (Section 7 flags the one field-format assumption to confirm)
MQTT broker | Not hosted as part of this submission — firmware targets a public test broker by default; point at your own broker for anything beyond a bench test
App-side subscriber | Real, working Dart/Flutter subscription code; not wired into a full map UI
Battery-life figures | Engineering estimates from datasheet-typical values, not hardware measurements — no physical hardware was available

Also assumed: LoRa P2P (not full LoRaWAN) end-to-end — the gateway receives P2P packets directly rather than acting as a LoRaWAN network-server gateway, which is simpler to implement completely within the timebox while still satisfying "gets a location fix into a mobile app over MQTT." Component prices in both BOMs are indicative single-unit distributor prices in INR as of September 2026, excluding GST, assembly labour, and enclosure hardware.

## 7. Cross-Document Consistency Review

The hardware, firmware, and bridge documentation were produced as separate, focused documents. Reading them together surfaced several genuine inconsistencies, ranked by how much they matter:

7.1 [Critical] Battery-life model assumes a regulator that isn't in the current BOM PAW_Power_Optimization_Strategy.docx models ~3 µA sleep current — a low-IQ regulator. But the collar schematic and BOM currently specify an AMS1117 LDO, whose ~5 mA quiescent draw Collar_Design_Notes.docx itself calls "the single biggest lever on standby battery life." At 5 mA continuous, a 1,000 mAh cell depletes in roughly 8 days regardless of GPS/LoRa activity — nowhere near the 6–8 month headline figures in Section 4.8. The low-IQ swap is listed as a production-run TODO in the design notes; until it is made, the long-runtime figures describe the production revision, not the schematic as currently drawn. Recommendation: either re-run Section 4.8's scenarios against the AMS1117's real quiescent current, or pull the low-IQ regulator forward into the current BOM before quoting a runtime number to anyone.

7.2 [Medium] Battery capacity isn't pinned to a single source of truth Collar_Design_Notes.docx's power-budget section assumes a 300 mAh cell; PAW_Power_Optimization_Strategy.docx models 1,000 mAh and 2,000 mAh scenarios; the BOM's battery line item (BT1) states no capacity at all. Recommendation: pin an exact cell part number and capacity in the BOM and have every downstream document reference that one number.

7.3 [Medium] LoRa bandwidth is assumed, not set, in the collar firmware hal_lora_init() in collar_firmware.cpp never calls a bandwidth setter, so it relies on an unstated RUI3 P2P default (assumed 125 kHz). gateway_bridge.ino does set it explicitly (LORA_BW=125) for its own RAK3172 configuration. Because both ends of a LoRa P2P link must agree on bandwidth to demodulate at all, the gateway's explicit setting is indirect evidence the collar is effectively at 125 kHz too — but it should be set explicitly on the collar side as well, since an unstated default is one RUI3 library update away from silently breaking the link.

7.4 [Medium] Airtime figure needs reconciling against the confirmed bandwidth
README.md and PAW_Power_Optimization_Strategy.docx cite ~60–70 ms airtime for the 18-byte payload. The worked calculation in PAW_LoRa_Radio_Configuration.docx (Section 4.6 of this document) gives ≈165–185 ms at 125 kHz — the bandwidth the gateway actually configures — and the ~70 ms figure only matches a 250 kHz / implicit-header case. Net effect on the battery-life numbers is small: GPS acquisition energy per event (~25 mA × 2–3 s ≈ 0.017–0.021 mAh) dominates LoRa TX energy at either airtime figure (~0.0023 mAh at 70 ms vs. ~0.0062 mAh at 185 ms), so Section 4.8's scenario totals would shift by roughly a percent or two once corrected — not enough to change which variable dominates, but enough that the airtime constant should be corrected for a fully defensible spec.

7.5 [Low] TX power constant mismatch between collar and gateway firmware collar_firmware.cpp sets LORA_TX_POWER=14 (dBm); gateway_bridge.ino sets LORA_POWER=15 for its own RAK3172's AT+P2P configuration. This doesn't break the link — a receiver's own TX power setting is irrelevant to how well it receives — but it's an unexplained inconsistency between the two firmware files' constants that should be reconciled or explicitly justified if the gateway is ever meant to transmit acks or downlinks.

7.6 [Low] Documented payload fields aren't actually published yet, and the app's de-dup logic references a field it never declares
MQTT_SCHEMA.md documents rssi, snr, gps_valid, motion_wake, and seq as payload fields, but gateway_bridge.ino currently leaves those five lines commented out in its JSON publish — only lat, lon, ts, battery_mv, and source go out today. Separately, app_subscriber.dart's _handleMessage compares location.seq for de-duplication, but the CollarLocation class as written declares no seq field and fromJson never parses one — so that de-dup path does not currently compile/run end-to-end, on top of the field not being sent yet by the gateway either. Recommendation: either uncomment the fields on the gateway and add seq to the Dart model, or drop seq-based de-dup entirely and rely on QoS-1's idempotent overwrite semantics, which MQTT_SCHEMA.md's own QoS rationale already argues is harmless.

7.7 [Low] +EVT:RXP2P field-format assumption is unverified
gateway_bridge.ino's own comments flag that some RUI3 firmware builds insert an extra length field before the hex payload in the +EVT:RXP2P: event line. The parser as written assumes a fixed three-field format (RSSI:SNR:HEX). This should be confirmed against the actual RUI3 firmware version's serial output before trusting the decoded fields on real hardware.

7.8 [Low] Timestamp is not wall-clock time
Already flagged clearly in MQTT_SCHEMA.md, restated here for visibility: ts is seconds since the collar last rebooted, not a UTC epoch. Any historical/timeline UI on the map needs either an RTC on the collar, real NMEA time-field parsing, or a gateway-side receipt timestamp (accepting sub-second LoRa transit delay) before ts can be treated as wall-clock time.

## 8. What I'd Do Differently With More Time

- Get real hardware on the bench to replace every datasheet-typical current figure in Section 4.8 with a measured one, and to confirm the actual +EVT:RXP2P field format the target RUI3 firmware version emits.
- Resolve the regulator/battery-life mismatch (Section 7.1) by re-running the battery scenarios against the AMS1117's real quiescent current, or by moving the low-IQ regulator into the current BOM instead of deferring it to the 1,000-unit revision.
- Wire up the payload fields MQTT_SCHEMA.md documents but the gateway currently leaves commented out, and fix app_subscriber.dart's CollarLocation model so its sequence-based de-dup actually compiles and runs (Section 7.6).
- Set LoRa bandwidth explicitly in the collar firmware instead of relying on an unstated default (Section 7.3), and reconcile the TX power constants between the two firmware files (Section 7.5).
- Give the collar an RTC, or have the gateway stamp ts on receipt, so the map can show wall-clock time instead of seconds-since-boot.
- Add battery discharge protection to the collar (TP4056 only manages charging) and a defined input/regulation stage to the gateway board (its schematic currently assumes a bare 3.3 V rail with no shown supply path) before either design is production-ready.
- Add a real battery-voltage divider/ADC path detail to the collar schematic rather than relying solely on RUI3's api.system.bat.get() abstraction, so the hardware and firmware documentation agree on exactly how that measurement is taken.

## 9. Evaluation Criteria Cross-Reference

Evaluation criterion | Where addressed
Correctness/clarity of RF & antenna reasoning | Sections 3.1, 3.2 (antenna placement), 4.5–4.6 (radio config, airtime, duty cycle)
Correctness/clarity of power-budget reasoning | Sections 3.1, 3.2 (hardware power budgets), 4.7–4.8 (firmware power strategy, battery life)
Code quality and readability (firmware + bridge) | part2-firmware/collar_firmware.cpp, part3-bridge/gateway_bridge.ino, part3-bridge/app_subscriber.dart
Sound low-power embedded design (sleep, wake sources, duty cycling) | Sections 4.2–4.3, 4.7
MQTT/protocol design judgment (topics, payload, QoS) | Section 5.2–5.3
Documentation clarity — can another engineer pick this up | This document in full, plus README.md's run instructions; Section 7's consistency review in particular is meant to show the reasoning another engineer would need, not just a clean final answer

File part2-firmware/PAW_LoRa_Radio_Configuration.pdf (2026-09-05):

# PAW

# LoRa Configuration

### 868 MHz P2P Radio Parameters

Rationale, Airtime Calculation & ETSI EU868 Duty-Cycle Compliance

Version 1.0
September 2026
Target Hardware: RAKwireless RAK3172 / STM32WLE5

PAW – LoRa Configuration

Version 1.0 | Page 2 of 4

## 1. Overview

This document specifies the LoRa Point-to-Point (P2P) radio configuration used by the PAW collar for transmitting location packets to a gateway over a private 868 MHz link. It states the exact parameters configured in firmware, explains the rationale behind each value, calculates on-air time for the fixed 18-byte payload, and checks the configuration against ETSI EU868 duty-cycle and power limits. Section 6 flags one parameter — channel bandwidth — that is not explicitly set in the current firmware and should be confirmed before the airtime and duty-cycle figures here are treated as final.

## 2. Radio Parameters

Parameter | Value | Firmware Constant
Frequency | 868 MHz (EU868) | LORA_FREQUENCY = 868000000UL
Radio Mode | LoRa Point-to-Point (P2P) | api.lora.nwm.set()
Spreading Factor | SF9 | LORA_SPREADING_FACTOR = 9
Coding Rate | 4/5 | LORA_CODING_RATE = 0
Preamble Length | 8 symbols | LORA_PREAMBLE = 8
TX Power | 14 dBm | LORA_TX_POWER = 14
Bandwidth | Not explicitly set — RUI3 default assumed (125 kHz) | — (see Section 6)
Payload Size | 18 bytes, fixed | PACKET_LEN = 18

All values other than bandwidth are set explicitly in hal_lora_init() via the RUI3 api.lora.* interface and are reproduced verbatim from collar_firmware.cpp.

## 3. Parameter Rationale

### 3.1 Frequency — 868 MHz

868 MHz sits in the EU863-870 MHz ISM band, the standard license-free allocation for LoRa devices operating in Europe. It requires no cellular subscription or carrier agreement, consistent with the collar's design goal of avoiding SIM/cellular connectivity entirely.

### 3.2 Spreading Factor — SF9

SF9 is a mid-range spreading factor: higher SFs (SF10–SF12) extend range and receiver sensitivity at the cost of significantly longer airtime and higher energy per packet, while lower SFs (SF7–SF8) shorten airtime but reduce link margin. SF9 was chosen as a balance point for a wearable tracker that needs reasonable range without materially increasing the active-radio time already budgeted in the power design. This is a tunable parameter — see Section 7.

### 3.3 Coding Rate — 4/5

4/5 is the least redundant of LoRa's forward-error-correction coding rates (4/5 through 4/8). It adds the minimum overhead needed for basic error correction, keeping airtime as short as possible; higher coding rates (4/6–4/8) trade additional airtime for more robustness against interference, which is not currently judged necessary for a short, private P2P link.

### 3.4 Preamble — 8 Symbols

8 symbols is the LoRa standard default preamble length. It is long enough for the receiver to reliably detect and synchronize to the incoming signal without adding unnecessary fixed overhead to every transmission.

### 3.5 TX Power — 14 dBm

14 dBm (25 mW) is a deliberate mid-range setting, not the radio's maximum. It also happens to align exactly with the ERP limit ETSI imposes on the primary EU868 sub-band (Section 5), so it is already compliant with the regulatory ceiling for that band rather than being throttled down from a higher default.

Implementation note: This value should be revisited once real-world link-margin needs from field testing are known — headroom exists only in the g3 sub-band (10% duty cycle / 27 dBm), not in the band currently configured.

## 4. Payload & Airtime

The payload is fixed at 18 bytes (PACKET_LEN) regardless of event type — see the Binary Packet Specification document for the exact field layout. Because LoRa airtime scales directly with payload size for a given SF/CR/BW combination, keeping the packet small and fixed-length is itself a power- and compliance-relevant design choice: every transmission costs the same, predictable amount of on-air time.

### 4.1 Worked Airtime Calculation

Using the standard LoRa airtime formulas (symbol duration = 2^SF / BW; preamble time = (n_preamble + 4.25) × symbol duration; payload symbol count per the Semtech formula for SF9, CR 4/5, an 18-byte payload, and CRC enabled):

Assumption | Explicit header + CRC | Implicit header + CRC
Bandwidth = 125 kHz (RUI3 default) | ≈ 185.3 ms | ≈ 164.9 ms
Bandwidth = 250 kHz | ≈ 92.7 ms | ≈ 82.4 ms

Discrepancy noted: Prior PAW documents
(README.md, Power Optimization Strategy) cite an
airtime of “~60–70 ms” for this payload. That figure is closest to the 250 kHz / implicit-header case above, not the 125 kHz explicit-header case that RUI3's P2P mode uses unless configured otherwise — see Section 6.

## 5. Regulatory Compliance — EU868 (ETSI EN 300 220)

The EU863-870 MHz ISM band is divided into sub-bands, each with its own duty-cycle and power ceiling under ETSI EN 300 220. The collar's configured frequency (868 MHz) and TX power (14 dBm) place it in sub-band g1:

Sub-band | Frequency Range | Max Duty Cycle | Max ERP
g1 (M) | 868.0 – 868.6 MHz | 1.0% | 25 mW (14 dBm)
g2 (N) | 868.7 – 869.2 MHz | 0.1% | 25 mW (14 dBm)
g3 (P) | 869.4 – 869.65 MHz | 10.0% | 500 mW (27 dBm)
g4 (Q) | 869.7 – 870.0 MHz | 1.0% | 25 mW (14 dBm)

Sub-band g1 permits 36 seconds of cumulative transmit time per hour (1% duty cycle) at up to 25 mW ERP (14 dBm) — exactly the TX power configured in firmware. At the ~185 ms airtime calculated in Section 4.1, the collar could transmit roughly 190 times per hour before approaching the duty-cycle ceiling; even at the ~70 ms figure used elsewhere, that rises to roughly 500 times per hour. The firmware's worst-case event rate from the Power Optimization Strategy document (348 events/day, ≈14.5/hour) sits well inside this margin under either airtime figure, so duty-cycle compliance is not at risk under the currently modeled usage — but the margin narrows considerably if SF or payload size increase in the future (Section 7).

## 6. Implementation Cross-Reference

Each configuration item above maps to a specific, verifiable construct in collar_firmware.cpp:

Configuration Item | Firmware Construct | Location
Frequency, SF, CR, preamble, TX power | api.lora.pfreq / psf / pcr / ppl / ptp | hal_lora_init()
P2P mode selection | api.lora.nwm.set() | hal_lora_init()
TX callback registration | api.lora.registerPSendCallb ack() | hal_lora_init()
Packet transmission | api.lora.psend(len, packet, false) | hal_lora_send()
Bench-test mock path | HW_LORA_MOCK build switch | hal_lora_send()

## 7. Open Items & Recommendations

- Confirm channel bandwidth: hal_lora_init() does not call an explicit bandwidth setter (e.g. api.lora.pbw). Confirm the RUI3 P2P default actually in effect on the RAK3172, and set it explicitly in firmware rather than relying on an unstated default — this single value changes the airtime estimate by roughly 2×.
- Reconcile the ~70 ms airtime figure used in README.md and the Power Optimization Strategy document against the worked calculation in Section 4.1 once bandwidth is confirmed, since it feeds directly into the battery-life tables in the Power Optimization Strategy document.
- Re-run the duty-cycle margin check in Section 5 against the confirmed airtime figure and against real field event rates once available, rather than the modeled worst case.
- Revisit SF9 / 14 dBm against measured field link margin once hardware testing begins; if range proves insufficient, sub-band g3 (869.4–869.65 MHz, 10% duty cycle, 27 dBm) offers substantially more headroom than g1, at the cost of moving off the currently configured frequency.
- If payload size or spreading factor change in a future protocol revision, re-run both the airtime calculation (Section 4.1) and the duty-cycle margin (Section 5) — neither is fixed once those inputs change.

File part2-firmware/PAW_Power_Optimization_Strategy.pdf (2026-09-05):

# PAW

# Power Optimization Strategy

### Detailed, Point-Wise Design Rationale

1000 mAh & 2000 mAh Li-Ion Scenarios — Current Draw Still an Engineering Estimate

Version 1.0
September 2026

PAW – Power Optimization Strategy

Version 1.0 | Page 2 of 6

## 1. Overview

The PAW collar's power strategy rests on keeping the MCU and its peripherals idle by default and only active for the minimum time a task requires. This document breaks that strategy into seven individual design decisions, ties each one to the specific firmware construct that implements it, and then addresses battery life directly. Section 6 estimates runtime for a 1000 mAh Li-Ion cell and Section 7 repeats the same calculation for a 2000 mAh alternative, both using clearly labeled datasheet-typical assumptions in place of measured current draw, since that and real-world duty cycle are still not measured on physical hardware. Sections 4 and 5 explain that gap and what closing it would require.

## 2. Power Optimization Techniques

### 2.1 Event-Driven Architecture — No Polling Loop

The firmware never busy-waits on a sensor or timer. The MCU's main loop does exactly one thing:

- loop() body is a single call to api.system.sleep.all() — there is no polling of GPIO state, sensor registers, or timers in the main loop.
- All work is dispatched from two sources only: a hardware interrupt (accelerometer) or a software timer callback (periodic fix) — both defined once in setup() and never re-armed manually.
- This matters because a polling loop keeps the CPU clocked and active continuously, which is one of the largest avoidable current draws on a battery-powered MCU; an interrupt/timer-driven design lets the MCU's own low-power sleep state handle idle time instead of firmware logic.

### 2.2 Accelerometer Interrupt Instead of Continuous MCU Polling

Motion detection is delegated entirely to the LIS2DW12, which runs its own low-power wake-up detection independently of the MCU:

- LIS2DW12_CTRL1 = 0x10 configures the accelerometer's own low-power output data rate (12.5 Hz) — it evaluates the motion threshold (LIS2DW12_WAKE_UP_THS) on-chip, without any help from the MCU.
- attachInterrupt(ACC_INT_PIN, accelerometerISR, RISING) wires the accelerometer's INT1 pin directly to a hardware interrupt — the MCU only wakes when motion has already been detected, not to check whether it occurred.
- The ISR itself is minimal by design: it sets a flag and starts a one-shot software timer (api.system.timer.start(RAK_TIMER_1, ...)), deferring all I2C, GPS, and radio work to motionHandler() running outside interrupt context. Keeping the ISR short avoids blocking other interrupts and avoids doing slow bus transactions (I2C/UART) inside interrupt context.

### 2.3 GPS Activated Only When a Fix Is Actually Required

The GPS receiver is not queried opportunistically or on a fast background schedule — only when a location report is about to be sent:

- hal_gps_acquire_fix() is called exclusively from motionHandler() and periodicHandler() — i.e. only at the moment a transmission is being prepared, never speculatively.
- Acquisition is bounded by GPS_FIX_TIMEOUT_MS (60,000 ms) — if a fix cannot be obtained within 60 seconds, the attempt is abandoned rather than left running indefinitely, capping the worst-case GPS-on duration per event.
- A build-time mock mode (HW_GPS_MOCK) exists purely for bench development without GPS hardware attached; it has no bearing on the production power design, where real GPS acquisition follows the same bounded on-demand pattern.

### 2.4 LoRa Radio Enabled Only During Transmission

The radio is not left in a listening or idle-powered state between events:

- hal_lora_send() / api.lora.psend() is invoked once per completed acquire-and-report cycle — a single bounded transmission, not a maintained radio session.
- TX power is fixed at 14 dBm (LORA_TX_POWER) — a deliberate mid-range setting rather than the radio's maximum; higher power extends range at direct energy cost per packet, so this value should be revisited once real-world link-margin needs are known.
- The payload is a fixed, compact 18 bytes (PACKET_LEN) — at SF9/CR 4/5, on-air time scales with payload size, so keeping the packet small directly shortens radio-on time per transmission.

### 2.5 MCU Returns to Low-Power Mode After Every Transmission

Both event handlers are designed to finish and hand control back to sleep, not to linger:

- motionHandler() and periodicHandler() are one-shot service routines — once transmitLocation() returns, execution falls back through loop() into api.system.sleep.all() with no intermediate active-wait step.
- api.system.lpm.set(1) and api.system.lpmlvl.set(2) (the RAK3172's deepest supported low-power level) are configured once in setup(), so the MCU's baseline idle current is minimized by default rather than needing to be re-entered manually after each event.

Implementation note: The current firmware does not send an explicit power-down/standby command to the GPS module between fixes — UART inactivity alone does not guarantee a GNSS chip drops to a low-power state on all modules. This should be verified against the MAX-M10S's power management interface before production, as it directly affects the sleep-current figure used in any battery-life calculation.

### 2.6 Motion Transmission Cooldown (Debounce)

Motion detection and location reporting are deliberately decoupled so that continuous activity cannot flood the radio:

- MOTION_COOLDOWN_MS (120,000 ms / 2 minutes) suppresses a new motion-triggered GPS+LoRa cycle if one already ran within the cooldown window, even if the accelerometer keeps firing interrupts.
- Without this, a continuously active animal could cross the motion threshold many times per minute, each one triggering a full GPS acquisition and LoRa transmission — by far the two most energy-expensive operations in the whole cycle.
- The cooldown effectively bounds the worst-case duty cycle from motion alone, independent of how active the animal actually is, which is the single biggest lever this firmware has over real-world battery drain.

### 2.7 Guaranteed Maximum 30-Minute Periodic Update

A fixed floor on update frequency exists independently of motion activity:

- MAX_FIX_INTERVAL_MS (1,800,000 ms / 30 minutes) drives a periodic timer that runs regardless of whether any motion has occurred — the collar is never silent for hours if the animal is resting.
- This is a deliberate trade-off: the 30-minute floor adds a small, fixed, predictable amount of active-current use per day, in exchange for a bounded worst-case reporting gap — unlike the motion path, this component of power draw is not data-dependent and can be estimated precisely once per-event current is measured.
- A secondary, currently unverified benefit: regular fixes may keep the GPS receiver's ephemeris data warm, which typically shortens time-to-fix (and therefore GPS-on current-time) on the next acquisition — this depends on the MAX-M10S's specific warm-start behavior and has not been measured on this design.

## 3. Implementation Cross-Reference

Each strategy point above maps to a specific, verifiable construct in collar_firmware.cpp:

Strategy Point | Firmware Construct | Location
Event-driven architecture | loop() → api.system.sleep.all() | Main loop
Accelerometer interrupt | attachInterrupt(ACC_INT_PIN, accelerometerISR, RISING) | hal_accel_init()
On-demand GPS | hal_gps_acquire_fix(), GPS_FIX_TIMEOUT_MS | motionHandler(), periodicHandler()
Bounded LoRa TX | hal_lora_send(), LORA_TX_POWER, PACKET_LEN | transmitLocation()
Return to sleep | api.system.lpm.set(1), api.system.lpmlvl.set(2) | setup()
Motion cooldown | MOTION_COOLDOWN_MS | motionHandler()
30-minute floor | MAX_FIX_INTERVAL_MS, RAK_TIMER_0 | setup(), periodicHandler()

## 4. Battery Life: Why a Single Figure Is Still Not Stated

A defensible battery-life figure depends on three inputs, combined over time. One of the three is now known; the other two have not been measured on physical hardware for this design:

- Battery capacity (mAh) — confirmed as 1000 mAh Li-Ion (see Section 6).
- Measured current draw per state — sleep current, GPS-acquisition current, and LoRa TX current are, at best, typical datasheet figures until measured on the assembled board; actual draw is affected by board revision, antenna matching, voltage regulator efficiency, and temperature, none of which a datasheet number captures.
- Real-world duty cycle — the 30-minute periodic floor is fixed and predictable, but the motion-triggered rate depends entirely on how active a given animal actually is, which varies by animal and environment and cannot be assumed.

Position taken in this document: With capacity now known but current draw and duty cycle still
unmeasured, Section 6 reports a range of scenario-based estimates rather than one number, and labels every input that is assumed rather than measured. Section 5 describes the remaining measurement work needed to collapse that range to a single reliable figure.

## 5. What Would Be Needed to Produce a Reliable Estimate

The following measurement steps would need to happen on physical hardware before a battery-life figure could be reported with any confidence:

- Bench-measure current draw in each defined firmware state (sleep, GPS acquiring, LoRa transmitting) on the assembled board, using a current-measurement instrument capable of resolving both the microamp-level sleep current and the higher-current active bursts.
- Log real event counts from bench or field testing — specifically, how many motion-triggered transmissions occur per day for a representative animal — rather than assuming a rate.

- Combine the two: average current (mA) = time-weighted sum of (state current × time in that state) across a full day, incorporating both the fixed 30-minute floor and the measured motion-triggered rate.
- Battery life (hours) = battery capacity (mAh) ÷ average current (mA), using the actual capacity of the cell selected for the final build.
- Report the resulting figure alongside the assumptions it depends on (battery capacity used, measured or modeled current values, assumed event rate) and label it explicitly as an engineering estimate rather than a guaranteed runtime.

## 6. Battery Life Estimate — 1000 mAh Li-Ion

Battery capacity has now been confirmed as 1000 mAh Li-Ion. This closes one of the three inputs identified in Section 4 as missing; the other two — measured current draw and real-world duty cycle — are still not measured on physical hardware. The figures below therefore use clearly labeled datasheet-typical assumptions in place of measured current, and a small set of duty-cycle scenarios in place of an assumed single event rate, so the result is presented as a range rather than a single number.

### 6.1 Assumed Parameters (Not Measured)

Parameter | Assumed Value | Basis
Battery capacity | 1000 mAh | Stated Li-Ion cell capacity (confirmed for this calculation)
Sleep current | 3 µA | RAK3172 LPM2 (~1.8 µA) + LIS2DW12 low-power wake mode (~1–2 µA) — datasheet typical, not measured
GPS acquisition current | 25 mA | MAX-M10S acquisition current — datasheet typical, not measured
GPS warm-start time | 2 s | Typical warm start with valid ephemeris — assumed
GPS cold-start time | 30 s | Typical cold start, no valid ephemeris — assumed
LoRa TX current | 120 mA | RAK3172 TX current at 14 dBm — datasheet typical, not measured
LoRa TX time | ~70 ms | Calculated airtime for the 18-byte payload at SF9 / CR 4/5

### 6.2 Calculation Method

For each scenario: GPS energy = GPS current × GPS time × events/day; LoRa energy = TX current × TX time × events/day; sleep energy = sleep current × 24 h. The three are summed to a daily mAh figure, and estimated life = 1000 mAh ÷ daily mAh.

### 6.3 Scenario Results

Scenario | mAh / day | Est. Days | Est. Months
Warm-start GPS, periodic only (48 events/day) | 0.851 | 1176 | ~38.7
Warm-start GPS, moderate motion (98 events/day) | 1.662 | 602 | ~19.8

Warm-start GPS, high motion (348 events/day) | 5.717 | 175 | ~5.8
Cold-start GPS, periodic only (48 events/day) | 10.184 | 98 | ~3.2
Cold-start GPS, moderate motion (98 events/day) | 20.717 | 48 | ~1.6

Reading this table: The roughly 20× spread between the best case (~39 months) and worst case (~1.6 months) is driven almost entirely by whether the GPS performs a warm start or a cold start on each fix — sleep current and LoRa airtime barely move the result by comparison. Once hardware is available, measuring warm-start vs. cold-start GPS behavior across the 30-minute periodic interval is the single highest-value measurement for narrowing this range, ahead of refining the sleep-current or LoRa-current assumptions.

This section remains an estimate, not a specification: all current-draw figures are datasheet-typical values substituted for measurement, and the event-rate scenarios are illustrative rather than derived from observed animal behavior. It should be superseded by the measurement plan in Section 5 as soon as physical hardware is available.

## 7. Battery Life Estimate — 2000 mAh Li-Ion (Alternative Capacity)

This section repeats the Section 6 calculation for a larger 2000 mAh Li-Ion cell, using the exact same assumed current-draw parameters (Section 6.1) and the same calculation method (Section 6.2). Daily energy consumption per scenario is unchanged — doubling battery capacity does not change how much current the collar draws, only how long a fixed capacity lasts against that draw. Every caveat in Section 6 about assumed, unmeasured values applies equally here.

### 7.1 Scenario Results (2000 mAh)

Scenario | mAh / day | Est. Days | Est. Months
Warm-start GPS, periodic only (48 events/day) | 0.851 | 2351 | ~77.3
Warm-start GPS, moderate motion (98 events/day) | 1.662 | 1204 | ~39.6
Warm-start GPS, high motion (348 events/day) | 5.717 | 350 | ~11.5
Cold-start GPS, periodic only (48 events/day) | 10.184 | 196 | ~6.5
Cold-start GPS, moderate motion (98 events/day) | 20.717 | 97 | ~3.2

Reading this table: Doubling capacity from 1000 mAh to 2000 mAh roughly doubles every runtime figure from Section 6, as expected — the best case moves from ~39 months to ~77 months, and the worst case from ~1.6 months to ~3.2 months. The dominant variable is unchanged: whether GPS warm-starts or cold-starts on each fix still accounts for the majority of the spread, not the choice of battery capacity. A larger cell buys headroom against that uncertainty, but does not resolve it — the measurement plan in Section 5 is still the only way to narrow the range itself.

As with Section 6, this is a scenario-based engineering estimate, not a specification, and should be superseded by measured current draw and observed duty cycle once physical hardware is available.

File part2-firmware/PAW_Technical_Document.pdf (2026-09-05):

# PAW

# LoRa-Based Pet Tracking Collar

### Firmware Development & Technical Deliverables

Low-Power LoRa P2P Pet Tracking System

Version 1.0
September 2026

Target Hardware: RAKwireless RAK3172 / STM32WLE5
GPS: u-blox MAX-M10S | Accelerometer: LIS2DW12 | Radio: LoRa P2P, 868 MHz

PAW – LoRa Pet Tracking Collar

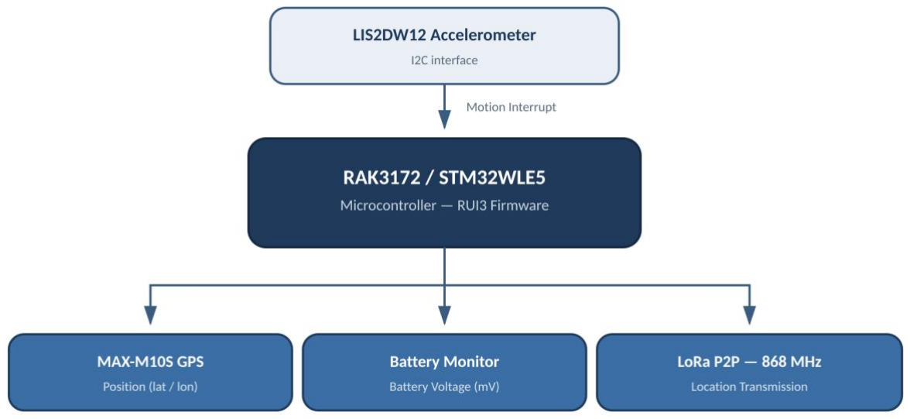
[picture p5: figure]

Version 1.0 | Page 2 of 5

## 1. Project Overview

PAW is a battery-powered pet tracking collar built around LoRa Point-to-Point (P2P) radio communication, with no cellular modem or SIM connectivity. The collar reports the animal's location by transmitting compact binary packets over a private 868 MHz LoRa link, either in response to detected motion or on a fixed periodic schedule. This document describes the firmware architecture, operating sequence, packet format, radio configuration, and power design of the collar, and lists the technical deliverables produced for this development phase.

## 2. System Architecture

The collar's hardware is organized around a single low-power microcontroller that arbitrates between three peripherals: an accelerometer for motion-based wake-up, a GNSS receiver for position, and a LoRa radio for transmission. Battery voltage is sampled internally by the MCU.

Fig. 1 — System architecture: MCU coordinates GPS, battery monitoring, and LoRa P2P transmission.

## 3. Firmware Operating Sequence

On each wake event, the firmware executes the following sequence before returning to low-power sleep:

- Low-power sleep — MCU remains in its lowest power state between events.
- Motion interrupt or periodic wake-up — the accelerometer's motion interrupt, or the 30-minute periodic timer, wakes the MCU.
- GPS acquisition — the GNSS receiver is powered/queried to obtain a position fix, bounded by a fix timeout.
- GPS validation — a fix is accepted only if the reported fix quality is valid; failed fixes are logged and the payload's GPS-valid flag is cleared.
- Battery measurement — the MCU samples its battery voltage for inclusion in the payload.
- Binary payload construction — device ID, position, timestamp, battery voltage, and a sequence number are packed into a fixed-length binary payload.
- LoRa P2P transmission — the payload is transmitted over the configured 868 MHz P2P link.

- Return to low-power sleep — radio and non-essential peripherals are left idle and the MCU resumes deep sleep until the next event.

## 4. Professional State Machine Diagram

The diagram below shows the firmware's state machine. Two independent wake-up sources — the accelerometer motion interrupt and the 30-minute periodic fix timer — both enter the same WAKE / EVENT DETECTION state, after which the sequence is identical regardless of which source triggered it.

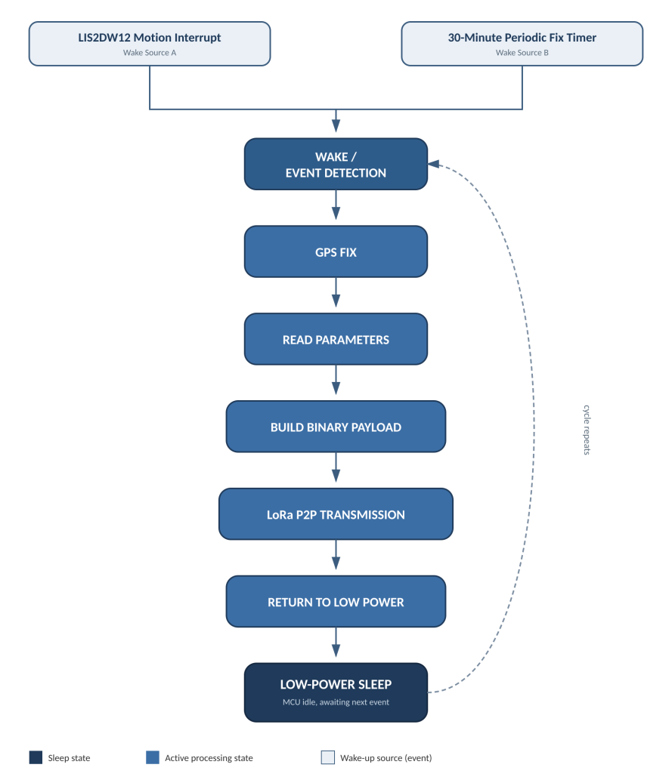
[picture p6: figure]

Fig. 2 — Collar firmware state machine, showing both wake-up paths converging on a common processing sequence.

## 5. Binary Packet Format

Each location report is encoded as an 18-byte binary payload using little-endian byte order.

Byte | Field | Type | Description
0 | Device ID | uint8 | Unique collar identifier
1 | Protocol Version | uint8 | Packet format version
2 | Status Flags | uint8 | Bit 0: GPS valid Bit 1: motion-triggered wake
3–6 | Latitude | int32 | Degrees × 1,000,000

Byte | Field | Type | Description
7–10 | Longitude | int32 | Degrees × 1,000,000
11–14 | Timestamp | uint32 | Seconds since boot
15–16 | Battery | uint16 | Battery voltage, millivolts
17 | Sequence | uint8 | Packet sequence number (wraps at 256)

Total payload size: 18 bytes. Encoding: little-endian.

## 6. Firmware Implementation

The firmware is organized around hardware-abstraction functions for each peripheral subsystem, so the control logic (wake handling, fix acquisition, payload construction, transmission) is decoupled from the specific driver calls beneath it:

- Accelerometer — LIS2DW12 initialization, interrupt configuration, and interrupt-source clearing.
- GPS — NMEA GGA sentence acquisition and parsing over UART.
- Battery measurement — MCU battery voltage sampling.
- LoRa P2P — radio configuration and packet transmission.
- Low-power management — sleep mode entry and low-power level configuration.

Implementation note: GPS acquisition supports a mock mode for development and bench testing when physical GNSS hardware is unavailable, generating a simulated fix in place of live NMEA data. The LoRa radio path is unaffected by this switch and remains configured for real P2P transmission at all times. Real NMEA GGA parsing is implemented and used automatically once GPS hardware is attached and mock mode is disabled.

## 7. LoRa Configuration

Parameter | Value
Frequency | 868 MHz
Mode | LoRa P2P
Spreading Factor | SF9
Coding Rate | 4/5
Preamble | 8 symbols
TX Power | 14 dBm

## 8. Power Optimization Strategy

The firmware's power strategy is event-driven rather than polling-based: the MCU remains in a low-power mode by default and is only woken by the accelerometer's motion interrupt or by the periodic fix timer, avoiding any continuous polling loop that would keep the processor active. The GPS receiver is activated only when a location fix is actually required, rather than being left powered continuously, and the LoRa radio is enabled only for the duration of a transmission before returning to an idle state. A motion transmission cooldown prevents repeated triggering from continuous movement, limiting how often a motion event can initiate a full acquire-and-transmit cycle. Independently of motion activity, a maximum 30-minute periodic update guarantees the collar is not silent for extended periods, while still keeping the MCU in low-power sleep between events. After each transmission the MCU disables non-essential peripherals and returns to low-power mode.

Engineering estimate: Any battery-life figure for this design depends on the specific battery capacity used
and on measured average current draw across sleep and active states, neither of which has been characterized on physical hardware at this stage. A battery-life number is not stated here; it should be calculated once a battery capacity is selected and current draw is measured or modeled against the actual fix rate in deployment, and clearly labeled as an estimate when reported.

## 9. Firmware State Description

State | Function
LOW-POWER SLEEP | MCU remains in low-power mode, awaiting a wake-up event.
WAKE | Detect and identify the wake-up source (motion interrupt or periodic timer).
GPS FIX | Acquire and validate a GNSS position fix within the fix timeout.
READ PARAMETERS | Read battery voltage and event context (motion vs. periodic).
BUILD PAYLOAD | Encode position, timestamp, battery, and sequence data into the binary payload.
LoRa TX | Transmit the binary packet over the configured LoRa P2P link.
RETURN TO SLEEP | Disable unnecessary peripherals and resume low-power mode.

## 10. Deliverables Summary

The following technical deliverables accompany this document:

- Firmware Source Code — RUI3-based collar firmware with hardware-abstraction layer and mockable GPS.
- State Machine Diagram — sleep / wake / fix / transmit / sleep cycle with both wake-up paths shown.
- Binary Packet Specification — 18-byte, little-endian payload format.
- LoRa Configuration — 868 MHz P2P radio parameters (SF9, CR 4/5, 8-symbol preamble, 14 dBm).
- Power Optimization Strategy — event-driven design rationale, with battery life left as an open engineering estimate pending measured current data.

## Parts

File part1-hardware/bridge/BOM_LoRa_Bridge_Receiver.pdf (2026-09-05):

# BILL OF MATERIALS

## LoRa Receiver Side (MQTT Bridge) Circuit

Currency: Indian Rupee (₹) | Quantity basis: 1 unit (prototype)
# | Ref. Des. | Component | Description / Value | Package | Qty | Unit Cost (₹) | Total Cost (₹)

### 1. Reset System Section

1 | R9 | Resistor | 10 kΩ pull-up (VCC to switch node) | 0603 | 1 | 1 | 1
2 | SW1 | SW_Push_Dual | Tactile push-button switch, reset line | SMD | 1 | 11 | 11
3 | C8 | Ceramic Capacitor | 100 nF, debounce | 0603 | 1 | 1 | 1

### 2. ESP32 Host MCU Section

4 | U2 | ESP32-DEVKIT-V1 | ESP32-WROOM-32 dev board (host
MCU, UART bridge to LoRa module) | Module | 1 | 400 | 400

### 3. MCU / LoRa Section (RAK3172)

5 | U1 | RAK3172-xx-B-SM-xl | STM32WLE5-based LoRa module (868 MHz) | SMD-32 | 1 | 980 | 980
6 | C2, C5, C6 | Capacitor | 100 nF x2, 10 µF x1, decoupling | 0603/0805 | 3 | 3 | 9
7 | E2 | ANT-868-PW-RA | 868 MHz tilt/swivel 1/4-wave monopole whip antenna, 4 dBi, screw-mount | Screw-mount | 1 | 310 | 310
8 | J1* | SMA Bulkhead Connector | RF feed for E2 (assumed; not explicit on schematic) | Panel-mount | 1 | 40 | 40

### 4. PCB & Mechanical

9 | — | Custom PCB | 2-layer FR4 fabrication (per unit, low
volume) | — | 1 | 350 | 350
ESTIMATED GRAND TOTAL (per unit) | ₹ 2,102

Notes
1. Unit costs are approximate, indicative retail/distributor prices in Indian Rupees (₹) for single-unit / prototype quantities, based on Indian and international distributor listings as of September 2026. Actual prices vary with vendor, package variant, and exchange rate.
2. Prices exclude GST, shipping/freight, PCB assembly (SMT) labour, and enclosure/mechanical hardware not shown on the schematic.
3. *J1 (SMA bulkhead connector) is not explicitly drawn on the schematic but is the typical hardware needed to mount a screw-type external antenna like the ANT-868-PW-RA to an enclosure; included here as a reasonable assumption — omit if E2 mounts directly to a PCB-edge SMA footprint.
4. The RAK3172 module cost (and, at scale, the ESP32 board cost) drops significantly at volumes of 1000+ units — bulk/OEM pricing should be requested from distributors for production runs.
5. This BOM covers only the LoRa Receiver / MQTT Bridge side circuit shown in the supplied schematic (ESP32 host + RAK3172 LoRa module + reset circuit + antenna) — it does not include any power supply / battery charging section, which was not present on this schematic page.

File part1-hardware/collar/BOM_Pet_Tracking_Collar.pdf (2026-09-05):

# BILL OF MATERIALS

## LoRa-Based Pet Tracking Collar Unit

Currency: Indian Rupee (₹) | Quantity basis: 1 unit (prototype)
# | Ref. Des. | Component | Description / Value | Package | Qty | Unit Cost (₹)

Total Cost
(₹)

### 1. USB Type-C & CH340E Interface Section

1 | P1 | USB-C Receptacle | USB_C_Plug_USB2.0, 6-pin SMD | USB-C | 1 | 28 | 28
2 | U6 | CH340E | USB to UART Bridge IC | MSOP-10 | 1 | 49 | 49
3 | R7, R8 | Resistor | 22 Ω, USB D+/D- series | 0603 | 2 | 1 | 2
4 | C3 | Ceramic Capacitor | 100 nF, decoupling | 0603 | 1 | 1 | 1
5 | C4 | Ceramic Capacitor | 10 µF, decoupling | 0805 | 1 | 4 | 4

### 2. Battery & Voltage Controller Section

6 | U5 | TP4056-42-ESOP8 | Li-ion/LiPo Linear Charger IC | ESOP-8 | 1 | 28 | 28
7 | U4 | AMS1117-3.3 | 3.3 V LDO Voltage Regulator | SOT-223 | 1 | 17 | 17
8 | D1, D2 | Diode | Schottky / status indicator diode | SOD-123 | 2 | 6 | 12
9 | R1–R6 | Resistor | Charge-current set / status, misc. | 0603 | 6 | 1 | 6
10 | C1, C2 | Capacitor | 10 µF & 100 nF, input/output filter | 0805/0603 | 2 | 3 | 6
11 | BT1 | Li-ion/LiPo Battery Cell | 3.7 V single-cell rechargeable | Cell | 1 | 350 | 350

### 3. Reset System Section

12 | R9 | Resistor | 10 kΩ pull-up | 0603 | 1 | 1 | 1
13 | SW1 | SW_Push_Dual | Tactile push-button switch | SMD | 1 | 11 | 11
14 | C8 | Ceramic Capacitor | 100 nF, debounce | 0603 | 1 | 1 | 1

### 4. GPS Section (MAX-M10S)

15 | U2 | MAX-M10S | u-blox GNSS/GPS Module | LGA-18 | 1 | 1260 | 1260
16 | AE2 | GNSS Antenna | Passive chip/patch GPS antenna | SMD | 1 | 210 | 210

### 5. MCU / LoRa Section (RAK3172)

17 | U1 | RAK3172-xx-B-SM-xl | STM32WLE5-based LoRa Module | SMD-32 | 1 | 980 | 980
18 | C5, C6, C7 | Capacitor | 100 nF x2, 10 µF x1, decoupling | 0603/0805 | 3 | 3 | 9
19 | E1 | ANT-868-CHIP-T | 868 MHz Monopole Ceramic Chip Antenna | SMD | 1 | 168 | 168

### 6. Accelerometer Sensor Section

20 | U3 | LIS2DE12 | 3-Axis Digital Accelerometer | LGA-12 | 1 | 133 | 133

### 7. PCB & Mechanical

21 | — | Custom PCB | 2-layer FR4, fabrication (per unit, low volume) | — | 1 | 420 | 420
ESTIMATED GRAND TOTAL (per unit) | | | | | | | ₹ 3,696

Notes

1. Unit costs are approximate, indicative retail/distributor prices in Indian Rupees (₹) for single-unit / prototype quantities, sourced from Indian and international component distributors as of September 2026. Actual prices vary with vendor, package variant, and exchange rate.
2. Prices exclude GST, shipping/freight, PCB assembly (SMT) labour, and enclosure/mechanical hardware not shown on the schematic.
3. Costs of key modules (RAK3172 LoRa module, MAX-M10S GPS module) and the battery cell drop significantly at volumes of 1000+ units — bulk/OEM pricing should be requested from distributors for production runs.

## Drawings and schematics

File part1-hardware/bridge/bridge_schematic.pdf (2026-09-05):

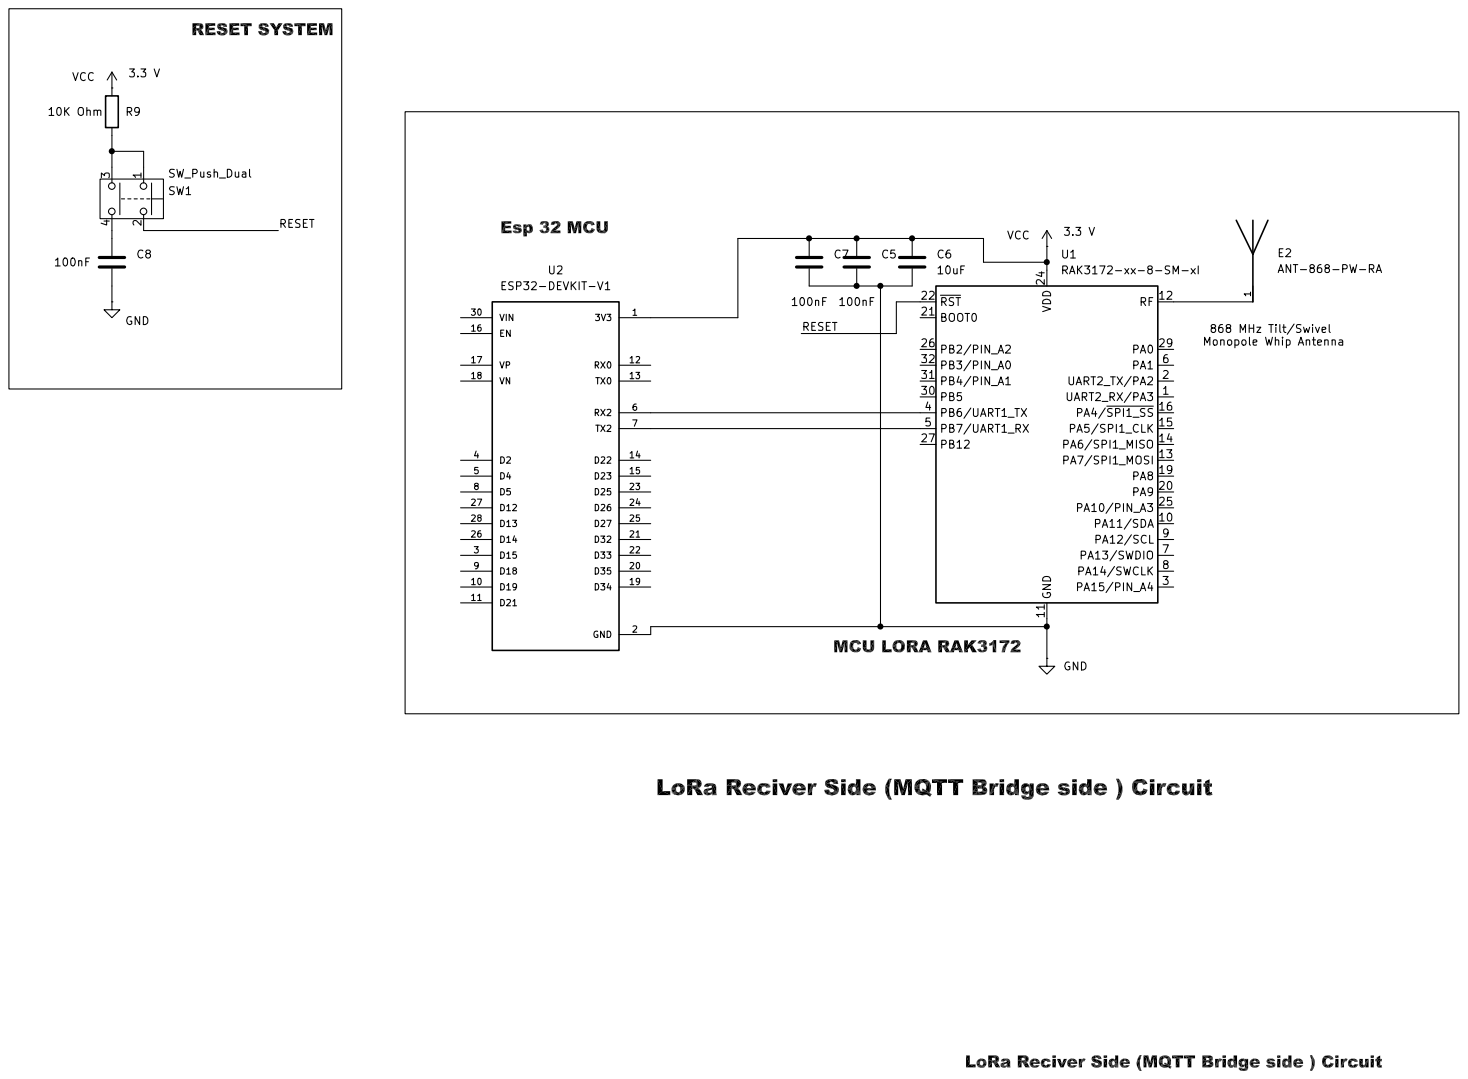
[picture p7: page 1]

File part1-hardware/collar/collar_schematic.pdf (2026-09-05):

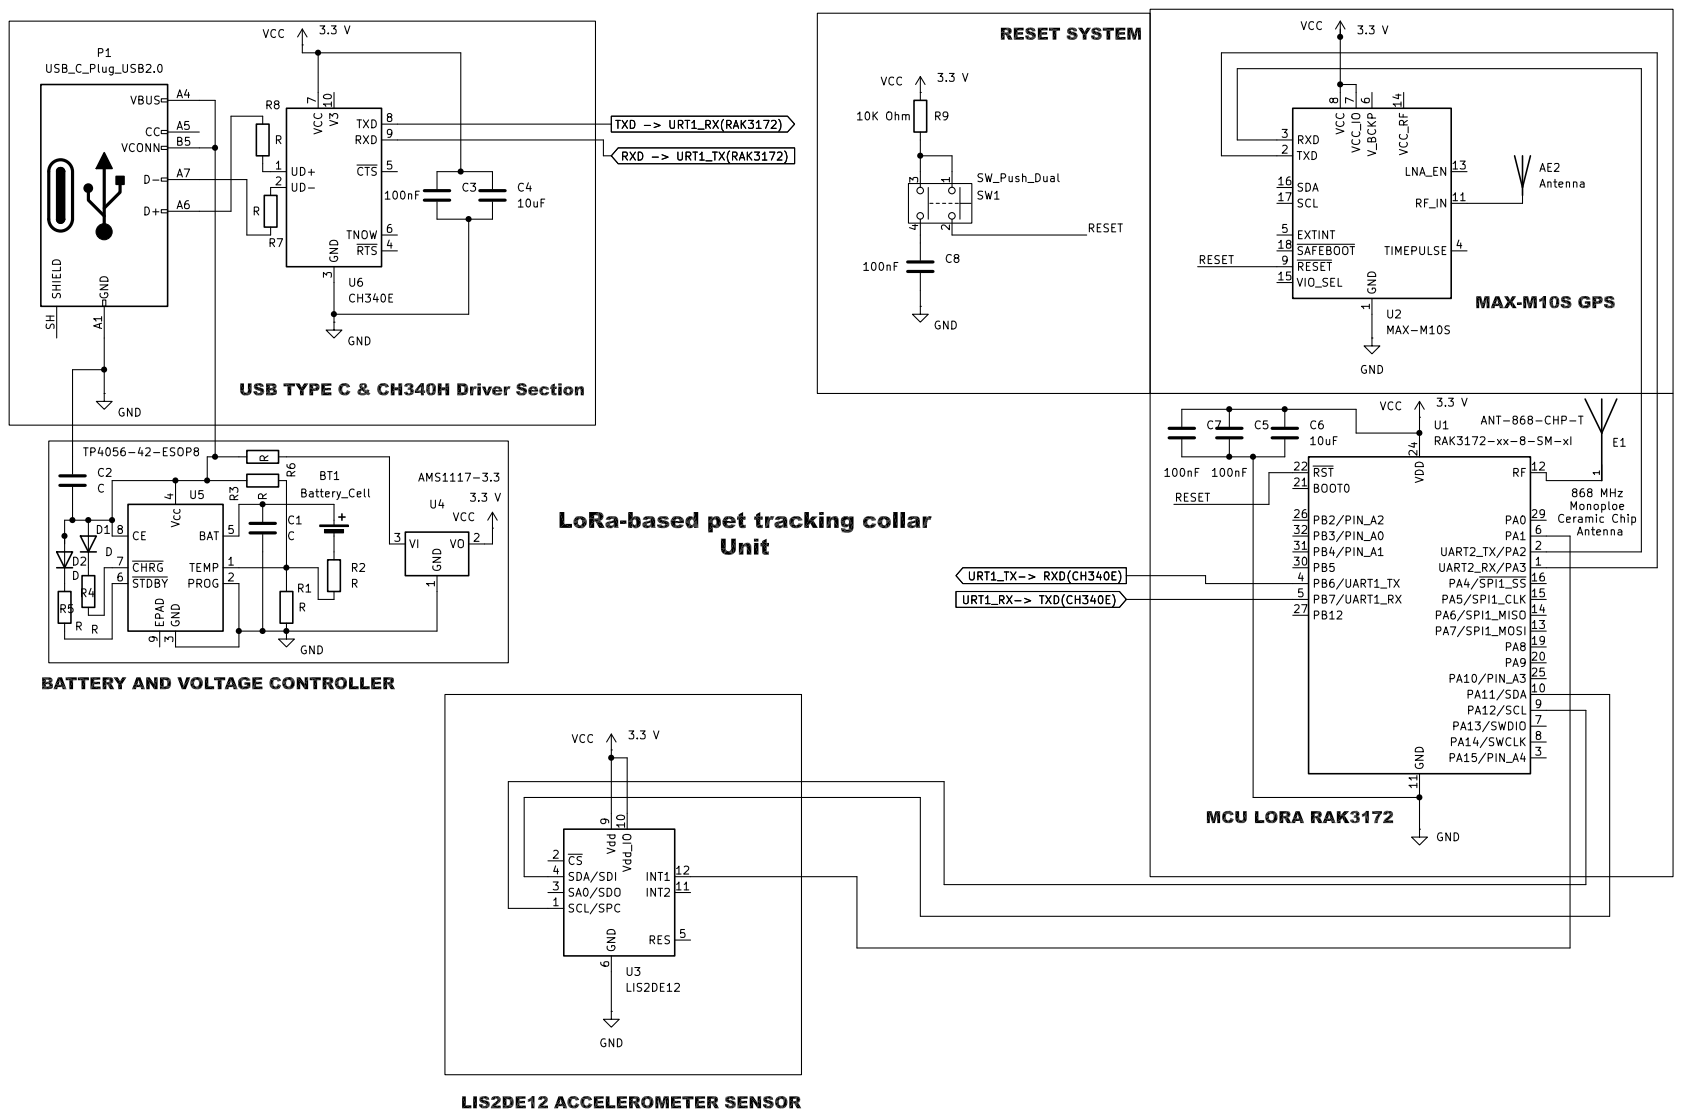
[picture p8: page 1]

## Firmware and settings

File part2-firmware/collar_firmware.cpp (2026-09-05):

/*
 * =====================================================================
 *  PAW PET TRACKER — Collar Firmware
 * =====================================================================
 *  Target      : RAKwireless RAK3172 (STM32WLE5) via RUI3 APIs
 *  Radio       : LoRa P2P, 868 MHz (EU868)
 *  GPS         : u-blox MAX-M10S over UART (NMEA GGA), mockable
 *  Accelerometer: ST LIS2DW12 over I2C, wake-on-motion interrupt
 *
 *  HARDWARE ABSTRACTION
 *  ---------------------------------------------------------------
 *  This file targets real RUI3 hardware but is structured so the
 *  hardware-facing calls are isolated behind small functions
 *  (hal_gps_*, hal_accel_*, hal_battery_*, hal_lora_*) so it can be
 *  ported to bare STM32 HAL, or run against the built-in GPS/LoRa
 *  simulators for bench testing without any radio/GPS hardware
 *  attached. Flip HW_GPS_MOCK / HW_LORA_MOCK below — no need to
 *  hunt through the logic to find where mocking happens.
 * =====================================================================
 */

#include <Arduino.h>
#include <Wire.h>

// =====================================================================
// BUILD-TIME HARDWARE SWITCHES  (flip these, nothing else)
// =====================================================================
#define HW_GPS_MOCK              1   // 1 = simulated NMEA fix, 0 = real MAX-M10S over UART
#define HW_LORA_MOCK             0   // 1 = log packets instead of radio TX (bench test w/o radio)

// =====================================================================
// CONFIGURATION
// =====================================================================
#define DEVICE_ID                0x01
#define PROTOCOL_VERSION         0x01

#define MAX_FIX_INTERVAL_MS      1800000UL     // 30 min: max silence even w/o motion
#define GPS_FIX_TIMEOUT_MS       60000UL       // give up on a fix after 60 s
#define MOTION_COOLDOWN_MS       120000UL      // min gap between motion-triggered TXs (2 min)

// LoRa P2P (EU868)
#define LORA_FREQUENCY            868000000UL
#define LORA_SPREADING_FACTOR     9
#define LORA_CODING_RATE          0             // 4/5
#define LORA_PREAMBLE             8
#define LORA_TX_POWER             14            // dBm

// GPS UART
#define GPS_BAUD                  9600
#define GPS_SERIAL                Serial1        // RAK3172 UART1 -> MAX-M10S

// LIS2DW12 (accelerometer)
#define LIS2DW12_ADDRESS          0x18
#define ACC_INT_PIN               WB_IO2

#define LIS2DW12_CTRL1            0x20
#define LIS2DW12_CTRL2            0x21
#define LIS2DW12_CTRL3            0x22
#define LIS2DW12_CTRL4_INT1       0x23
#define LIS2DW12_WAKE_UP_THS      0x34
#define LIS2DW12_WAKE_UP_DUR      0x35
#define LIS2DW12_WAKE_UP_SRC      0x38
#define LIS2DW12_CTRL7            0x3F

// =====================================================================
// PACKET LAYOUT  (18 bytes, all little-endian)
//   [0]      device_id
//   [1]      protocol_version
//   [2]      flags        bit0=gps_valid  bit1=motion_wake
//   [3..6]   latitude     int32,  degrees * 1e6
//   [7..10]  longitude    int32,  degrees * 1e6
//   [11..14] timestamp    uint32, seconds since boot
//   [15..16] battery_mv   uint16
//   [17]     seq          uint8, wraps at 256
// =====================================================================
#define PACKET_LEN 18

// =====================================================================
// GLOBAL STATE
// =====================================================================
volatile bool     g_motion_flag   = false;   // set in ISR, cleared once serviced
uint32_t          g_last_motion_tx_ms = 0;    // for motion cooldown
uint8_t           g_sequence      = 0;        // matches packed 1-byte field

bool     g_gps_valid     = false;
float    g_gps_lat       = 0.0f;
float    g_gps_lon       = 0.0f;
uint32_t g_gps_timestamp = 0;
uint16_t g_battery_mv    = 0;

// =====================================================================
// HAL: LIS2DW12 (I2C accelerometer)
// =====================================================================
static void lis2dw12_write(uint8_t reg, uint8_t value)
{
    Wire.beginTransmission(LIS2DW12_ADDRESS);
    Wire.write(reg);
    Wire.write(value);
    Wire.endTransmission();
}

static uint8_t lis2dw12_read(uint8_t reg)
{
    Wire.beginTransmission(LIS2DW12_ADDRESS);
    Wire.write(reg);
    Wire.endTransmission(false);
    Wire.requestFrom(LIS2DW12_ADDRESS, (uint8_t)1);
    return Wire.available() ? Wire.read() : 0;
}

// Forward decl for the ISR
void accelerometerISR();

static void hal_accel_init()
{
    lis2dw12_write(LIS2DW12_CTRL1, 0x10);       // 12.5 Hz, low-power mode 1
    lis2dw12_write(LIS2DW12_CTRL2, 0x00);
    lis2dw12_write(LIS2DW12_CTRL3, 0x40);       // latched interrupt
    lis2dw12_write(LIS2DW12_CTRL4_INT1, 0x20);  // wake-up event -> INT1
    lis2dw12_write(LIS2DW12_WAKE_UP_THS, 4);    // motion threshold
    lis2dw12_write(LIS2DW12_WAKE_UP_DUR, 0x00);
    lis2dw12_write(LIS2DW12_CTRL7, 0x20);       // interrupts enabled

    pinMode(ACC_INT_PIN, INPUT);
    attachInterrupt(ACC_INT_PIN, accelerometerISR, RISING);

    Serial.println("[HAL] LIS2DW12 initialized");
}

static inline void hal_accel_clear_int()
{
    lis2dw12_read(LIS2DW12_WAKE_UP_SRC);
}

// =====================================================================
// ACCELEROMETER ISR
// ---------------------------------------------------------------------
// Kept minimal on purpose: an ISR should only set a flag. All real
// work (I2C reads, GPS acquisition, LoRa TX) happens later in
// motionHandler(), running in normal (non-interrupt) context via the
// RUI3 timer/event dispatch, not directly inside the ISR.
// =====================================================================
void accelerometerISR()
{
    g_motion_flag = true;
    // Defer the actual handling to a one-shot software timer so all
    // I2C/UART/radio work happens outside interrupt context.
    api.system.timer.start(RAK_TIMER_1, 10, NULL);
}

// =====================================================================
// HAL: GPS
// =====================================================================
static double nmeaToDecimal(const char *value, char direction)
{
    if (value == NULL || strlen(value) < 3) return 0.0;
    double raw = atof(value);
    int degrees = (int)(raw / 100);
    double minutes = raw - (degrees * 100);
    double decimal = degrees + (minutes / 60.0);
    if (direction == 'S' || direction == 'W') decimal = -decimal;
    return decimal;
}

static bool parseGGA(char *sentence)
{
    if (sentence == NULL) return false;

    char *fields[15];
    int idx = 0;
    char *token = strtok(sentence, ",");
    while (token != NULL && idx < 15)
    {
        fields[idx++] = token;
        token = strtok(NULL, ",");
    }
    if (idx < 7) return false;

    int fix_quality = atoi(fields[6]);
    if (fix_quality == 0) return false;   // no fix

    g_gps_lat = nmeaToDecimal(fields[2], fields[3][0]);
    g_gps_lon = nmeaToDecimal(fields[4], fields[5][0]);
    g_gps_timestamp = millis() / 1000;
    g_gps_valid = true;
    return true;
}

#if HW_GPS_MOCK
// Simulated fix — jitters slightly around a fixed point so repeated
// packets aren't bit-identical, useful for bench-testing the receiver.
static void hal_gps_mock_fix()
{
    g_gps_lat = 22.864000 + ((float)(random(-50, 50)) / 100000.0f);
    g_gps_lon = 88.401000 + ((float)(random(-50, 50)) / 100000.0f);
    g_gps_timestamp = millis() / 1000;
    g_gps_valid = true;
    delay(500); // simulate acquisition latency
}
#endif

// Returns true on a valid fix within GPS_FIX_TIMEOUT_MS, false on timeout.
static bool hal_gps_acquire_fix()
{
    g_gps_valid = false;

#if HW_GPS_MOCK
    hal_gps_mock_fix();
    return g_gps_valid;
#else
    unsigned long start = millis();
    char sentence[150];
    uint16_t pos = 0;

    while ((millis() - start) < GPS_FIX_TIMEOUT_MS)
    {
        while (GPS_SERIAL.available())
        {
            char c = GPS_SERIAL.read();
            if (c == '\n')
            {
                sentence[pos] = '\0';
                if (strstr(sentence, "$GNGGA") || strstr(sentence, "$GPGGA"))
                {
                    if (parseGGA(sentence)) return true;
                }
                pos = 0;
            }
            else if (pos < sizeof(sentence) - 1)
            {
                sentence[pos++] = c;
            }
        }
        delay(5);
    }
    return false; // timed out — no fix
#endif
}

// =====================================================================
// HAL: battery
// =====================================================================
static inline uint16_t hal_battery_read_mv()
{
    return api.system.bat.get();
}

// =====================================================================
// PACKET ENCODING
// =====================================================================
static inline void writeLE32(uint8_t *buf, int32_t value)
{
    buf[0] = value & 0xFF;
    buf[1] = (value >> 8) & 0xFF;
    buf[2] = (value >> 16) & 0xFF;
    buf[3] = (value >> 24) & 0xFF;
}

static inline void writeLE16(uint8_t *buf, uint16_t value)
{
    buf[0] = value & 0xFF;
    buf[1] = (value >> 8) & 0xFF;
}

static uint8_t buildPacket(uint8_t *packet, bool motionWake)
{
    int32_t lat_e6 = (int32_t)(g_gps_lat * 1000000.0);
    int32_t lon_e6 = (int32_t)(g_gps_lon * 1000000.0);

    packet[0] = DEVICE_ID;
    packet[1] = PROTOCOL_VERSION;

    packet[2] = 0;
    if (g_gps_valid)  packet[2] |= (1 << 0);
    if (motionWake)   packet[2] |= (1 << 1);

    writeLE32(&packet[3], lat_e6);
    writeLE32(&packet[7], lon_e6);
    writeLE32(&packet[11], (int32_t)g_gps_timestamp);
    writeLE16(&packet[15], g_battery_mv);
    packet[17] = g_sequence++;   // wraps at 256 by design (uint8_t)

    return PACKET_LEN;
}

// =====================================================================
// HAL: LoRa P2P
// =====================================================================
static void loraSendCallback(void)
{
    Serial.println("[HAL] LoRa TX callback fired");
}

static void hal_lora_init()
{
#if !HW_LORA_MOCK
    api.lora.nwm.set();                     // P2P mode
    api.lora.pfreq.set(LORA_FREQUENCY);
    api.lora.psf.set(LORA_SPREADING_FACTOR);
    api.lora.pcr.set(LORA_CODING_RATE);
    api.lora.ppl.set(LORA_PREAMBLE);
    api.lora.ptp.set(LORA_TX_POWER);
    api.lora.registerPSendCallback(loraSendCallback);
#endif
    Serial.println("[HAL] LoRa P2P initialized (868 MHz)");
}

static bool hal_lora_send(uint8_t *packet, uint8_t len)
{
#if HW_LORA_MOCK
    Serial.print("[MOCK TX] ");
    for (uint8_t i = 0; i < len; i++) Serial.printf("%02X ", packet[i]);
    Serial.println();
    return true;
#else
    return api.lora.psend(len, packet, false);
#endif
}

static bool transmitLocation(bool motionWake)
{
    uint8_t packet[PACKET_LEN];
    uint8_t len = buildPacket(packet, motionWake);

    Serial.println("Sending LoRa P2P packet...");
    bool ok = hal_lora_send(packet, len);
    Serial.println(ok ? "LoRa packet queued" : "LoRa packet failed");
    return ok;
}

// =====================================================================
// EVENT HANDLERS  (run outside ISR context)
// =====================================================================

// Fired ~10 ms after a motion interrupt (deferred from the ISR).
void motionHandler(void *)
{
    if (!g_motion_flag) return;
    g_motion_flag = false;

    hal_accel_clear_int();

    // Debounce: ignore motion wakes that arrive within the cooldown
    // window of the last motion-triggered transmission, so continuous
    // movement doesn't hammer the radio/battery. The 30-min periodic
    // fix (below) still runs independently and is unaffected.
    uint32_t now = millis();
    if ((now - g_last_motion_tx_ms) < MOTION_COOLDOWN_MS)
    {
        Serial.println("Motion detected (debounced, skipping TX)");
        return;
    }

    Serial.println("Motion detected -> acquiring GPS...");

    if (hal_gps_acquire_fix())
    {
        Serial.printf("GPS fix: %.6f, %.6f\n", g_gps_lat, g_gps_lon);
        g_battery_mv = hal_battery_read_mv();
        transmitLocation(true);
        g_last_motion_tx_ms = now;
    }
    else
    {
        Serial.println("GPS fix failed (motion event)");
    }
}

// Fired every MAX_FIX_INTERVAL_MS regardless of motion.
void periodicHandler(void *)
{
    Serial.println("Periodic (30 min) location update");

    if (hal_gps_acquire_fix())
    {
        g_battery_mv = hal_battery_read_mv();
        transmitLocation(false);
    }
    else
    {
        Serial.println("Periodic GPS fix failed");
    }
}

// =====================================================================
// SETUP / LOOP
// =====================================================================
void setup()
{
    Serial.begin(115200);
    delay(1000);

    Serial.println();
    Serial.println("===============================");
    Serial.println(" PAW PET TRACKER - Collar Firmware");
    Serial.println(" LoRa P2P - 868 MHz");
    Serial.printf(" GPS mock: %s | LoRa mock: %s\n",
                   HW_GPS_MOCK ? "ON" : "OFF",
                   HW_LORA_MOCK ? "ON" : "OFF");
    Serial.println("===============================");

    Wire.begin();
    GPS_SERIAL.begin(GPS_BAUD);

    hal_accel_init();
    hal_lora_init();

    // One-shot timer: deferred motion handling (fires shortly after ISR)
    api.system.timer.create(RAK_TIMER_1, motionHandler, RAK_TIMER_ONESHOT);

    // Periodic timer: guarantees a fix at least every MAX_FIX_INTERVAL_MS
    api.system.timer.create(RAK_TIMER_0, periodicHandler, RAK_TIMER_PERIODIC);
    api.system.timer.start(RAK_TIMER_0, MAX_FIX_INTERVAL_MS, NULL);

#if defined(_VARIANT_RAK3172_) || defined(_VARIANT_RAK3172_SIP_)
    api.system.lpmlvl.set(2);   // deepest low-power mode the RAK3172 supports
#endif
    api.system.lpm.set(1);      // enable low power management

    Serial.println("System initialized, entering low power...");
}

void loop()
{
    // Everything is interrupt/timer driven — the MCU spends essentially
    // all of its time here, asleep.
    api.system.sleep.all();
}

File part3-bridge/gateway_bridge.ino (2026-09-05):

// ============================================================
// PAW LORA GATEWAY BRIDGE
// LoRa (RAK3172 P2P) -> ESP32 -> MQTT
// ============================================================
//
// Fixes applied vs original draft:
//  1. Timer callbacks now match TimerCallbackFunction_t's real
//     signature (void(TimerHandle_t)) instead of being cast from
//     no-arg functions (was undefined behavior).
//  2. Reconnect calls are guarded against overlapping attempts.
//  3. Added a retained MQTT Last-Will/status topic so the app
//     can tell if the gateway itself goes offline.
//  4. decodeAndPublish() now checks mqttClient.connected()
//     before attempting a publish, and reports drops distinctly
//     from encode/parse errors.
//  5. Flagged the +EVT:RXP2P: field assumption -- confirm against
//     your RAK3172 firmware's actual serial log; some RUI3 builds
//     insert a length field before the hex payload.
//
// ============================================================

#include <WiFi.h>
#include <AsyncMqttClient.h>
#include <ArduinoJson.h>

extern "C" {
#include "freertos/FreeRTOS.h"
#include "freertos/timers.h"
}

// ============================================================
// WIFI CONFIGURATION
// ============================================================

const char* WIFI_SSID     = "YOUR_WIFI_NAME";
const char* WIFI_PASSWORD = "YOUR_WIFI_PASSWORD";

// ============================================================
// MQTT CONFIGURATION
// ============================================================

const char* MQTT_HOST = "broker.hivemq.com";
const uint16_t MQTT_PORT = 1883;

const char* MQTT_USERNAME = "";
const char* MQTT_PASSWORD = "";

const char* MQTT_BASE_TOPIC   = "paw/collar";
const char* MQTT_STATUS_TOPIC = "paw/collar/gateway/status";

// ============================================================
// ESP32 <-> RAK3172 UART2
// ============================================================

#define RAK_RX_PIN 16   // ESP32 RX2 <- RAK3172 TX
#define RAK_TX_PIN 17   // ESP32 TX2 -> RAK3172 RX

HardwareSerial RAKSerial(2);

// ============================================================
// LORA P2P CONFIGURATION
// ============================================================

#define LORA_FREQUENCY 868000000UL
#define LORA_SF        9
#define LORA_BW        125
#define LORA_CR        0
#define LORA_PREAMBLE  8
#define LORA_POWER     15

// ============================================================
// PACKET CONFIGURATION
// ============================================================

#define PACKET_SIZE      18
#define PROTOCOL_VERSION 1

// ============================================================
// MQTT / RECONNECT STATE
// ============================================================

AsyncMqttClient mqttClient;

TimerHandle_t mqttReconnectTimer;
TimerHandle_t wifiReconnectTimer;

volatile bool wifiConnectInFlight = false;
volatile bool mqttConnectInFlight = false;

String rakLine;

// ============================================================
// FORWARD DECLARATIONS
// ============================================================

void connectToWiFi();
void connectToMQTT();
void processRAKLine(String line);
void decodeAndPublish(String hexPayload, int rssi, int snr);

// ============================================================
// WIFI CONNECT
// ============================================================

void connectToWiFi()
{
    if (wifiConnectInFlight || WiFi.status() == WL_CONNECTED)
        return;

    wifiConnectInFlight = true;

    Serial.println();
    Serial.println("Connecting to Wi-Fi...");

    WiFi.begin(WIFI_SSID, WIFI_PASSWORD);
}

// ============================================================
// MQTT CONNECT
// ============================================================

void connectToMQTT()
{
    if (WiFi.status() != WL_CONNECTED)
        return;

    if (mqttConnectInFlight || mqttClient.connected())
        return;

    mqttConnectInFlight = true;

    Serial.println("Connecting to MQTT broker...");

    mqttClient.connect();
}

// ============================================================
// TIMER CALLBACK WRAPPERS
// (xTimerCreate requires void(TimerHandle_t) exactly)
// ============================================================

void onWifiReconnectTimer(TimerHandle_t xTimer)
{
    wifiConnectInFlight = false;
    connectToWiFi();
}

void onMqttReconnectTimer(TimerHandle_t xTimer)
{
    mqttConnectInFlight = false;
    connectToMQTT();
}

// ============================================================
// WIFI EVENT
// ============================================================

void WiFiEvent(WiFiEvent_t event)
{
    switch (event)
    {
        case ARDUINO_EVENT_WIFI_STA_GOT_IP:

            wifiConnectInFlight = false;

            Serial.println();
            Serial.println("Wi-Fi connected");
            Serial.print("IP address: ");
            Serial.println(WiFi.localIP());

            connectToMQTT();

            break;

        case ARDUINO_EVENT_WIFI_STA_DISCONNECTED:

            wifiConnectInFlight = false;

            Serial.println();
            Serial.println("Wi-Fi disconnected");

            xTimerStop(mqttReconnectTimer, 0);
            xTimerStart(wifiReconnectTimer, 0);

            break;

        default:
            break;
    }
}

// ============================================================
// MQTT CALLBACKS
// ============================================================

void onMqttConnect(bool sessionPresent)
{
    mqttConnectInFlight = false;

    Serial.println();
    Serial.println("MQTT connected");
    Serial.print("Session present: ");
    Serial.println(sessionPresent);

    // Announce we're online (retained, so a newly-opened app
    // sees gateway status immediately).
    mqttClient.publish(MQTT_STATUS_TOPIC, 1, true, "online");

    Serial.println("MQTT location publishing enabled");
}

void onMqttDisconnect(AsyncMqttClientDisconnectReason reason)
{
    mqttConnectInFlight = false;

    Serial.println();
    Serial.println("MQTT disconnected");

    if (WiFi.status() == WL_CONNECTED)
    {
        xTimerStart(mqttReconnectTimer, 0);
    }
}

void onMqttPublish(uint16_t packetId)
{
    Serial.print("MQTT PUBACK received. Packet ID: ");
    Serial.println(packetId);
}

// ============================================================
// HEX HELPERS
// ============================================================

uint8_t hexCharToValue(char c)
{
    if (c >= '0' && c <= '9') return c - '0';
    if (c >= 'A' && c <= 'F') return c - 'A' + 10;
    if (c >= 'a' && c <= 'f') return c - 'a' + 10;
    return 0xFF;
}
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
